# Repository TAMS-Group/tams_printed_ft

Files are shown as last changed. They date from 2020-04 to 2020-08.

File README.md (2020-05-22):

# tams_printed_ft

This repository provides OpenSCAD 3D models together with the corresponding software
to build and assemble a family of low-cost 3D printed force and force/torque sensors.
While multi-axis force/torque sensors are readily available commercially from several vendors,
these a low-volume high-precision devices, and the corresponding costs and complex integration
have so far limited their wide deployment.

Our design approach combines 3D printable plastic structures with commodity optical sensors
and standard Arduino-style microcontrollers. The general sensor configuration, including
type and number of sensors, sensor layout, and structure of the elastic element can be chosen
freely according to the task. We provide a couple of example designs that have been optimized
for 3D printability using common FFF/FDM (fused filament fabrication / fused deposition modeling)
3D machines. The electronics can use custom circuit boards, but many of the sensors can also
be hand-wired without problem, and a working 6-axis force/torque sensor can be built for less
than 20 US dolloars, plus a few hours of 3D printing.

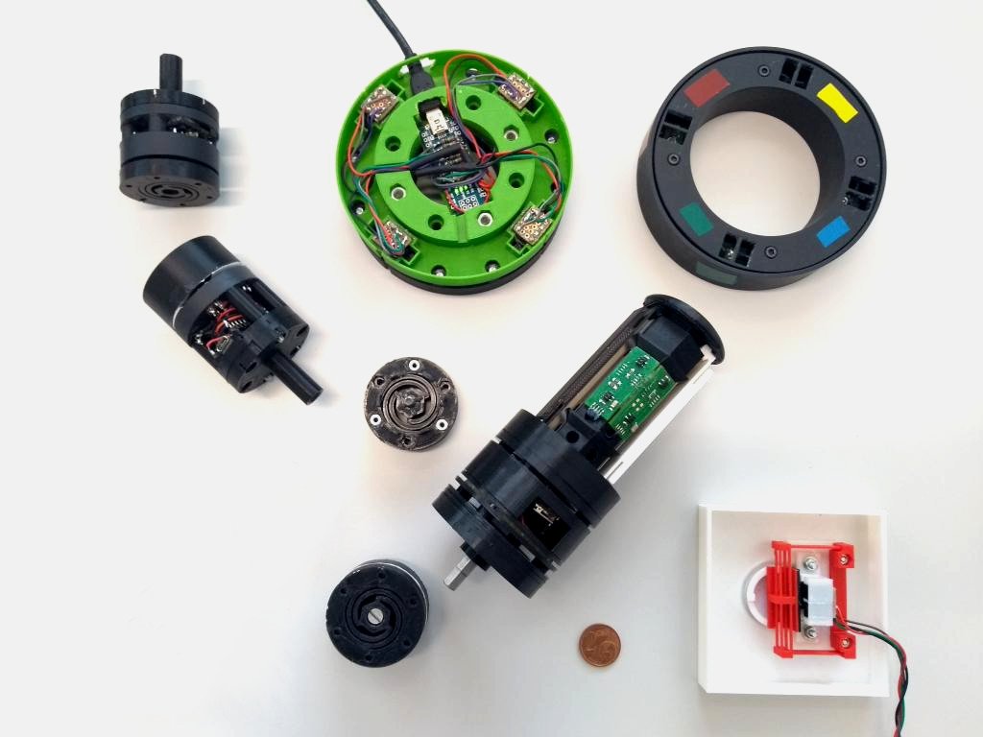
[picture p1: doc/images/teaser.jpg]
"3D printed f/t sensors"


## Note: stub while paper under review

This repository is currently a stub, as the journal paper describing the general approach
and several key algorithms is still under review. If you are a reviewer, please don't hesitate
to contact the authors (via the editors to keep your anonymity) 
for a preview of the final repository contents.

## Getting started

The following instructions assume that you want to build and use a force/torque sensor 
together with ROS. If so, please proceed as follows:

0. read this README and check the overview paper.

1. clone this repository into your catkin workspace, then build your workspace:
```
cd ~/catkin_ws/src
git clone github.com/TAMS-Group/tams_printed_ft
cd ~/catkin_ws
catkin_make
```

2. check the OpenSCAD and/or meshes subdirectories and select the sensor that you need.
Run OpenSCAD and edit the existing parameters or completely modify the sensor geometry.
Export the individual parts to STL meshes.

3. Use your favorite slicing software to convert all needed mechanical parts into G-Code
for your 3D-printer, then start printing the parts.

4. Check that you have the required electronics components (optical sensors, microcontroller,
pullup-resistors, capacitors, ...) and the mechanical components (screws and nuts).

5. Assemble the mechanical parts, insert the optical sensors or ready-made circuit boards,
and wire the optical sensors to the microcontroller/amplifier boards.

6. Connect the microcontroller to the host computer and upload/flash the corresponding
firmware. Modify the firmware according to your needs. Once powered up and flashed,
the microcontroller should start sending out raw sensor data, 
using the selected communication protocol (e.g. I2C/TWI, SPI, UART, USB),
baudrate (e.g. 115200 baud), etc.

7. Edit and update the launch files to match your setup (e.g. name of the root tf frame,
name of your robots and F/T sensor frames, sample rates, comunication device, etc.).

8. Run the ROS driver for the selected sensor, and check that the raw data looks ok:
```
roscore
roslaunch tams_printed_ft bottle_ft.launch  [device:=/dev/ttyUSB2 ...]
rosrun plotjuggler PlotJuggler -> start streaming -> /printed_ft/rawdata -> plot
```

9. Record calibration data
```
roslaunch tams_printed_ft bottle_ft_calibration_helper.launch
run experiment ... press control-c
python3 scripts/linear_bottle.py 
check calibration quality, select best algorithm, ...
cp /tmp/bottle_ft_huber_1e-4.yaml config/bottle_ft_calibration.yaml
```

10. Restart the sensor to use the recently created calibration file

## Directory Structure

What is in here? The basic structure of this repository is a common ROS catkin package, with a few extra directories for the OpenSCAD models and Arduino firmware:

* `config`: ROS configuration files, including example sensor calibration YAML files and rviz / plotjuggler configurations;
* `doc`: Misc documentation, including the overview paper, datasheets for the optical sensors, Arduino pinouts, and
  some images/screenshots;
* `firmware`: Arduino/Teensy source code for the sensor firmware; copy (or symlink) into your `~/Arduino/` folder to use.
* `launch`: ROS launch files for the sensor drivers and utilities;
* `meshes`: this subdirectory holds STL meshes ready for 3D printing for some of the sensors, as well as Collada .dae files needed for the ROS URDF models;
* `openscad`: Configurable OpenSCAD source code for some of our sensors. Most of the files will render an assembled model of the complete sensor, but individual parts can be enabled or disabled using the provided boolean variables. This directory also provides automated export scripts to generate 3D STL meshes for the individual 3D printable files;
* `nodes`: ROS Python driver nodes for the different sensors, as well as calibration scripts and plotting utilities;
* `scripts`: misc shell scripts
* `src`: ROS C++ source files, currently the calibration-helper tool and the radial-pattern generator;
* `urdf`: ROS URDF models for the sensors;
* `package.xml` and `CMakeLists.txt`: the common ROS catkin package description and build files.

Note that there are no header files (yet).

## Prototype sensors

* The most basic sensor consists of a deflecting beam mounted 
  to a suitable support structure, with an optical distance sensor
  (either reflex-type proximity sensor or fork-type interrupter) in between.
  A foot force sensor for a Robocup soccer humanoid:

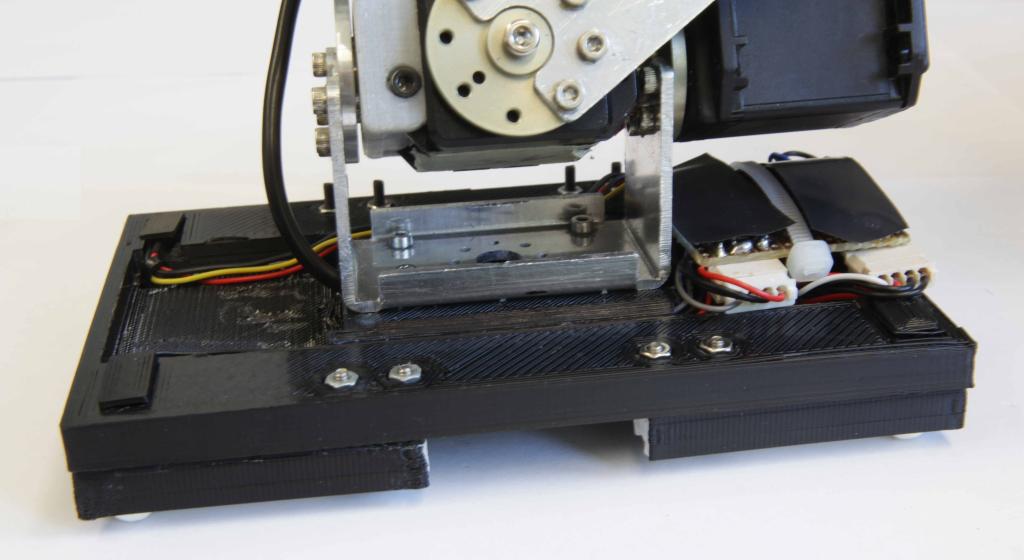
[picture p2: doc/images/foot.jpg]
"Robocup soccer foot sensor"
  

  <!--
  The OpenSCAD module described in our 
  <a href="https://tams.informatik.uni-hamburg.de/publications/2017/3D-Printed%20Low-Cost%20Modular%20Force%20Sensors.pdf">CLAWAR 2017 paper</a>
  can be used to dimension the cantilever for given maximum load.
   -->

* A convenient sensor module built from two fork-type photointerrupters, used as a basic components
  in several of our designs;

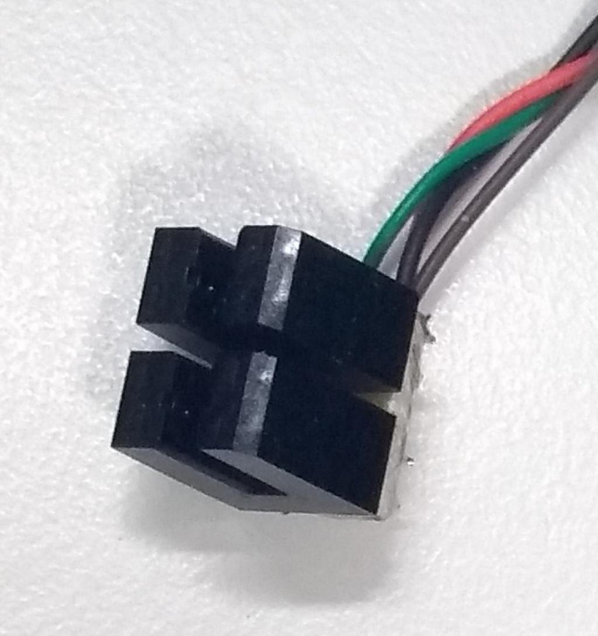
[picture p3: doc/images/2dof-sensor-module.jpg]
"2-DOF sensor module"
  

* One of these modules is than used as the basis of a simple 2-DOF sensor designed
  for measuring friction/shearing forces during object pushing experiments:

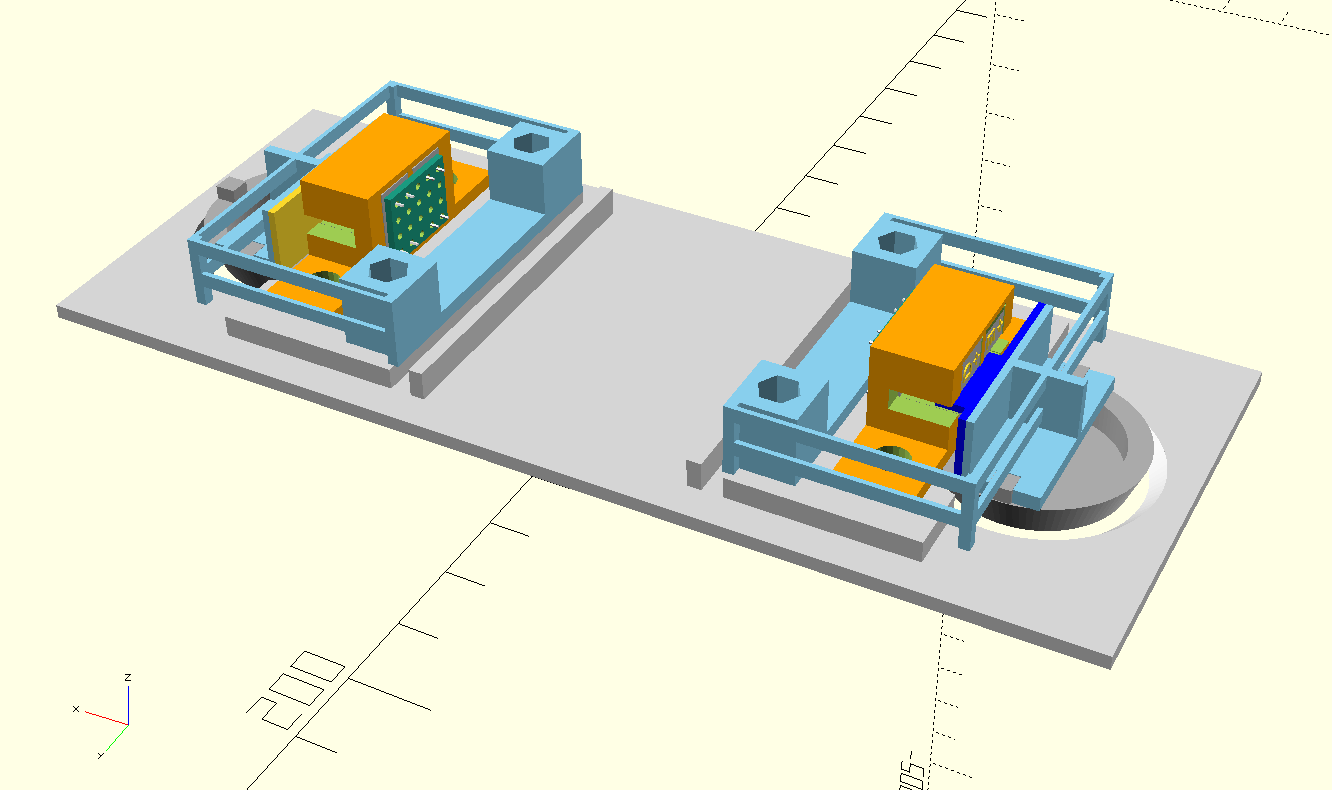
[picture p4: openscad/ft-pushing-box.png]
"pushing-box F/T sensor"
  

* All forces and torque applied to a rigid body can be integrated into one effective 
  net force (Fx,Fy,Fz) and one couple of forces resulting in torque (Mx,My,Mz).
  We include a large diameter six-axis force/torque sensor, using four of the 2-DOF sensor 
  modules presented above and grub-screws for initial zero-adjustment:

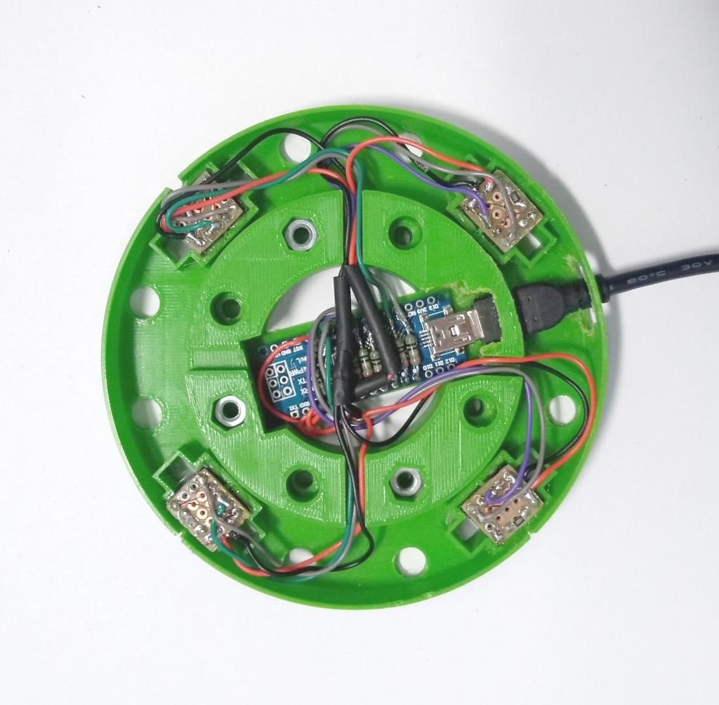
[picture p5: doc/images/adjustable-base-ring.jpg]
"adjustable six-axis F/T sensor"
  

* Unconventional shapes can be designed as well. As an example, we include 
  a ring-type six-axis force/torque sensor, using four 2-DOF sensor modules:

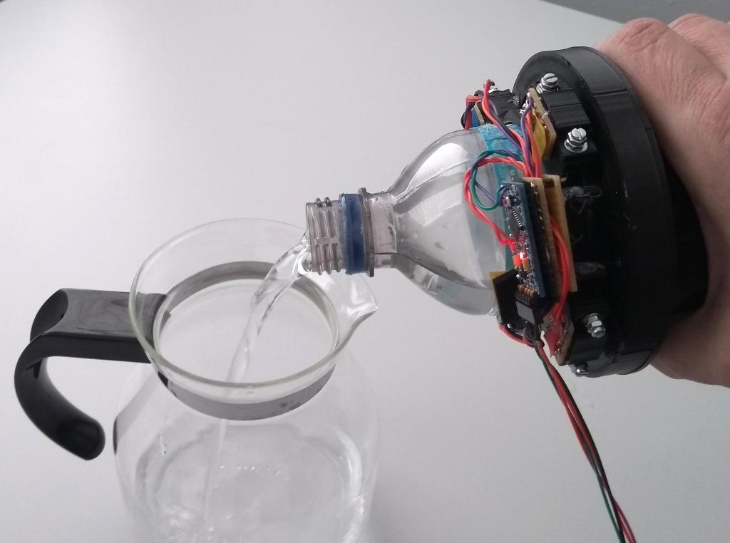
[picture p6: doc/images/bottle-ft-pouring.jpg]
"bottle-ft ring-type six-axis F/T sensor"
  

* 3D-printed springs can be designed at will, exactly matched to the task at hand.
  As an example, we present a 3D-elastic element with three sets of orthogonal levers,
  where force-range and torque-range can be selected individually for each axis.
  The corresponding prototype sensor also demonstrates the use of proximity sensors
  and a flat layout (PCB friendly) of the optical sensors and optional electronics:

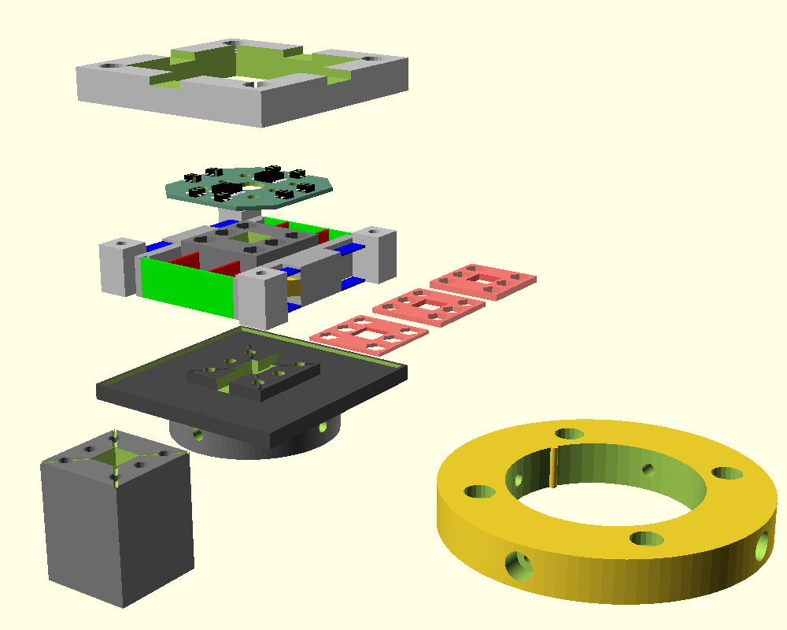
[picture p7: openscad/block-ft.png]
"block-ft six-axis F/T sensor"
  

## OpenSCAD designs and 3D printing

The sensors presented in the paper were all designed using the OpenSCAD software.
We recommend to use OpenSCAD to edit, update, and configure the basic sensor designs to your needs,
but we also provide a set of ready-made STL meshes ready for slicing and printing on your 3D printer.
Most of the meshes are optimized for 3D printability without support structures, 
just make sure to select the appropriate mesh orientation for printing (which should be obvious).
A few STL models contain overhanging parts and bridges; please check for the best mesh orientation
and experiment with different printer settings (including support structures) to find a suitable setup.

## Arduino firmware

While our example designs intentionally use different microcontrollers, 
the core program logic is always the same.
The basic hardware setup consists of a stabilized power supply for the infrared LEDs,
while the phototransistors are connected to pullup resistors and also directly to 
the analog input pins of the selected microcontrollers.

The program first configures the microcontroller output and input pins,
sets up and initializes the communication with the host computer 
and creates the data structures for raw-data filtering.
Communication is typically serial over USB, but also native USB when supported by the controller,
or UDP/WIFI for the wireless boards.

The main loop of the program then repeatedly reads the active analog input pins,
typically staring with one cold read to ensure that the analog voltage has stabilized,
followed by a few AD conversions to digitize the current illumination level.
Optionally, oversampling and filtering is applied.
Where applicable, LEDs might also be pulsed to reduce average power consumption and
to support dark current detection and measurement.

Raw output values are then sent to the host PC, together with sequence number and
health/error indication (overload, ambient light detection, breakage, etc.).
Due ensure high sample rates and low latencies, conversion to floating point 
and calibration is NOT performed on the microcontrollers.

## ROS drivers

## URDF models

We also provide ROS URDF models for the sensors, see the `urdf`subdirectory.
The modeling approach combines the actual (high-res) 3D meshes also used for 3D printing
for the visual model, while a simplified geometric model (cylinder, box) is used for
the sensor collision model.

The sensor model consists of several separate parts, each with their corresponding
TF frames, and linked by joints. Typically, the base frame of the sensor is centered
at the bottom of the static (robot-side) sensor mesh, the sensing joint is in the
middle of the sensor, and another tool-mount frame is provided at the upper end
of the (tool-side) sensor mesh.
We also provide the required yaml controller configuration files to enable
joint_states and wrench output from Gazebo simulation:

```
roscd tams_printed_ft
roslaunch tams_printed_ft gazebo_all_demo.launch
```

The screenshot below shows a collection of URDF sensor models as visualized in rviz:

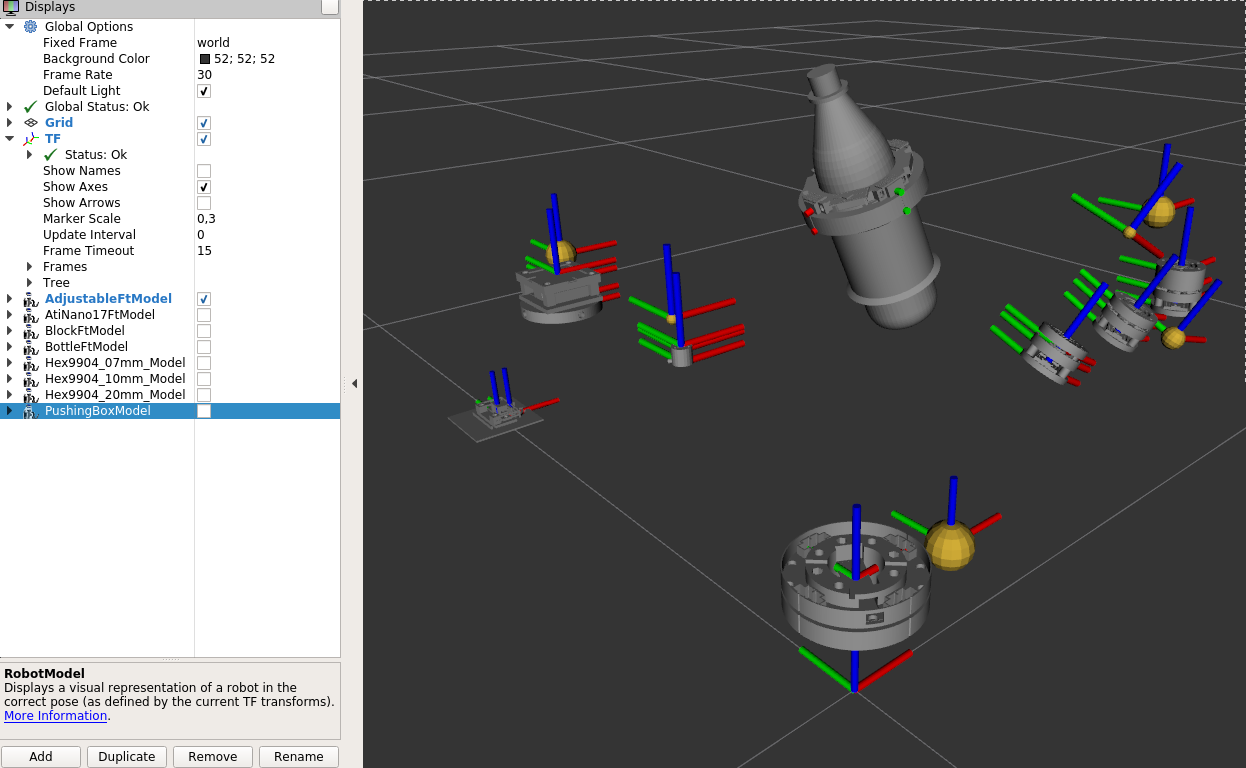
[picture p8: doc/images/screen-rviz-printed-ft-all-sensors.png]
"URDF models of the 3D printed f/t sensors in rviz"


For the small sensors, the tilt under load cannot be ignored, and should be modeled 
using a generic a six-DOF joint between the base (robot side) and swiveling (tool side)
parts of the sensor. 

However, at the moment only single-axis revolute joints are used in the models;
Gazebo will still calculate the complete wrench, but only one axis is actuated
(e.g., roll), while the other axes (e.g. pitch and yaw) remain at zero.

For the real sensor, publishing estimated deflection as `joint_states` message
is planned, but has not been implemented yet. Instead, our sensor launch scripts 
also run `static_transform_publisher` nodes that publish the required transformation
(from sensor base part to deflecting sensor tool part) 
to guarantee a connected tf tree along the kinematic chain. 
By default, we use the all-zero (no deflection, no tilt) transformation, 
but you might want to update the corresponding parameters if your sensor is mostly
used in one orientation and payload.

## Sensor calibration

As described in the paper, all standard approaches can be used to calibrate the sensor(s),
and Python scripts are provided to calculate calibration matrices for a tested sensor.
Calibration against a second reference sensor is of course easiest, and typically only
requires to edit and configure the geometric layout between the 3D printed and the existing
reference sensor in the sensor launch file(s).

## Tips and tricks

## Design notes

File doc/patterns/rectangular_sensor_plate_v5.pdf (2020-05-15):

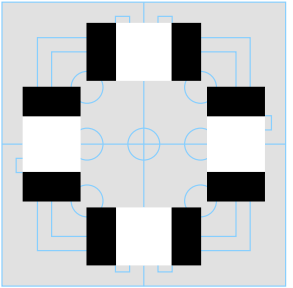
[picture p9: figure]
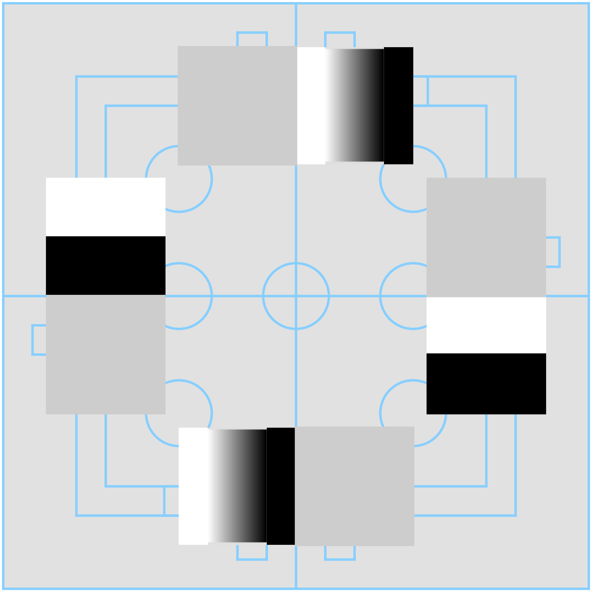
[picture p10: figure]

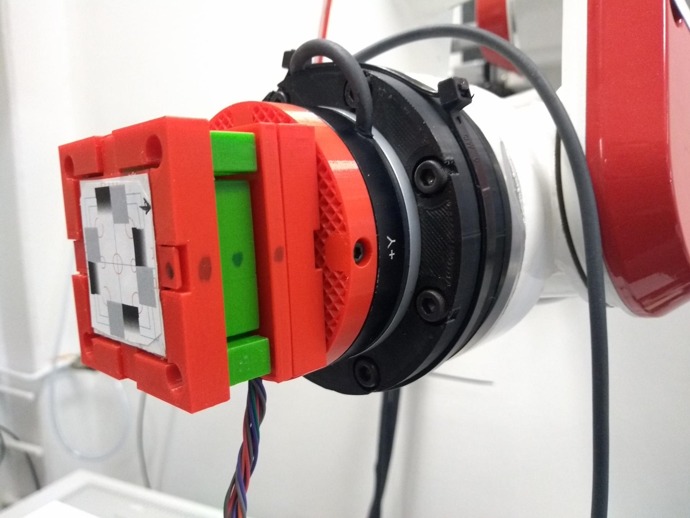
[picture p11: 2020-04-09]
doc/images/block-ft-on-pa10.jpg

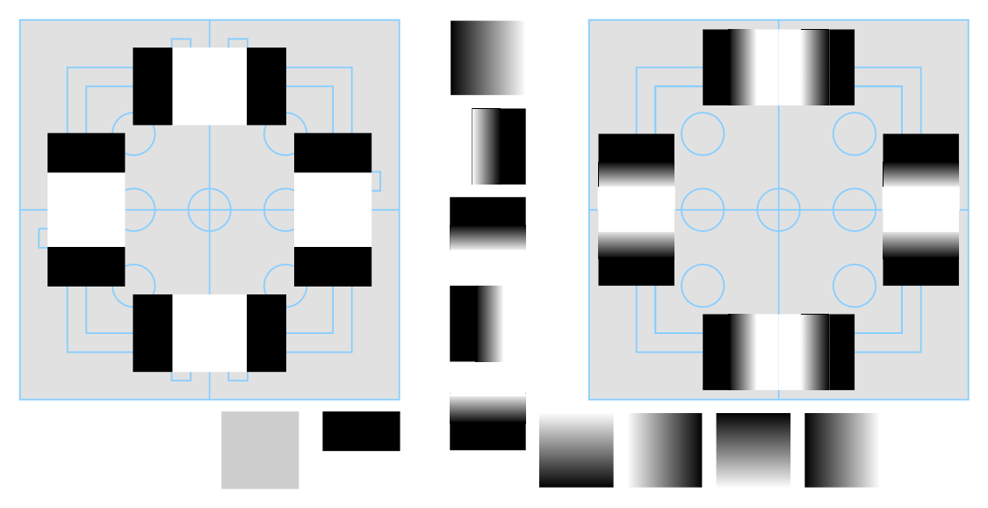
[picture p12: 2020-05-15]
doc/patterns/jfig_rectangular_sensor_plate_v5.png

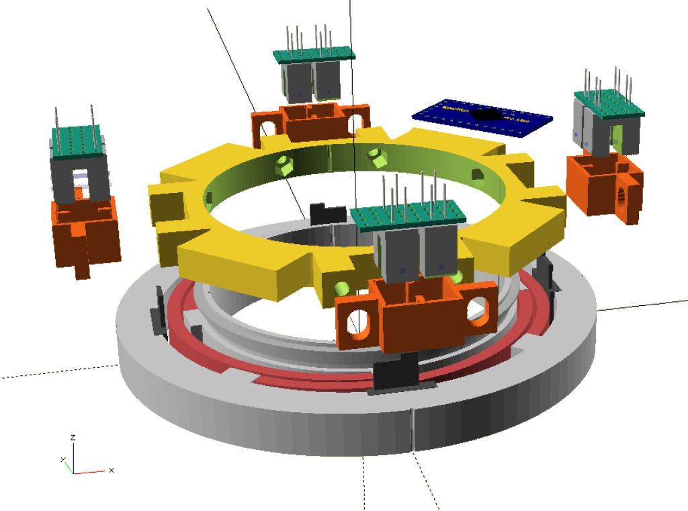
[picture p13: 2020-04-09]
doc/images/bottle-ft-exploded.png

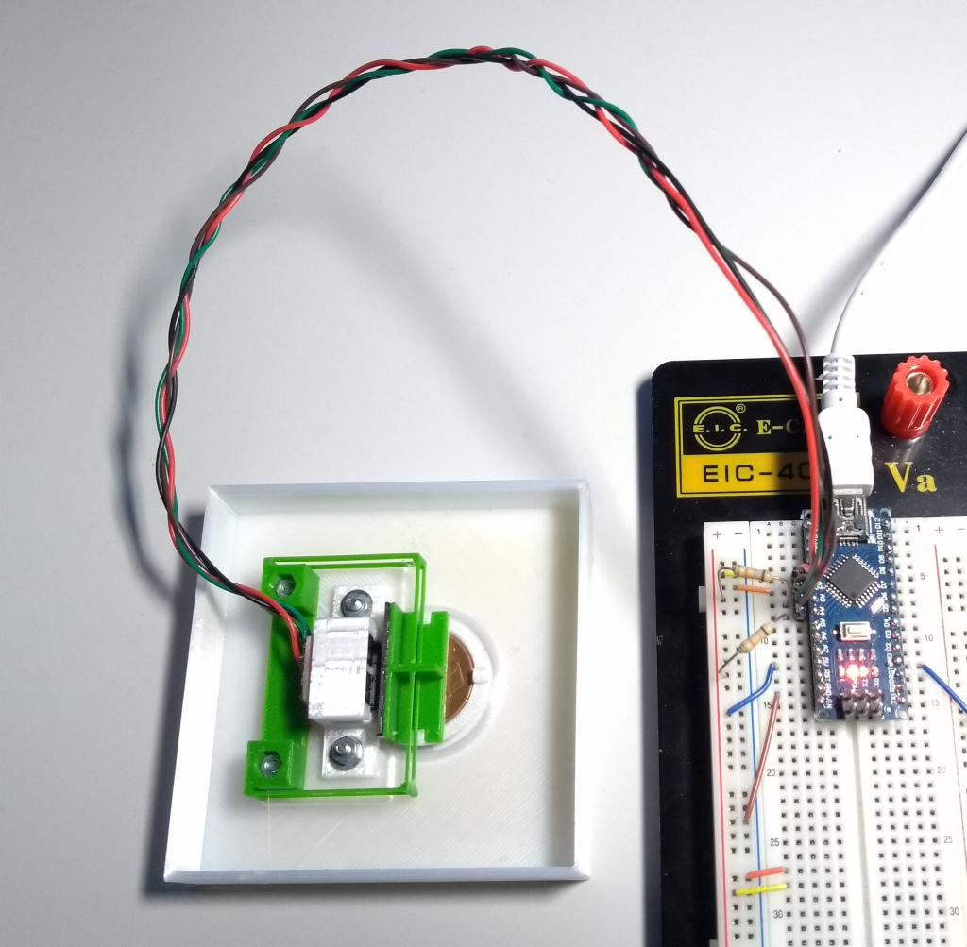
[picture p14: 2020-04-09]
doc/images/pushing-box.jpg

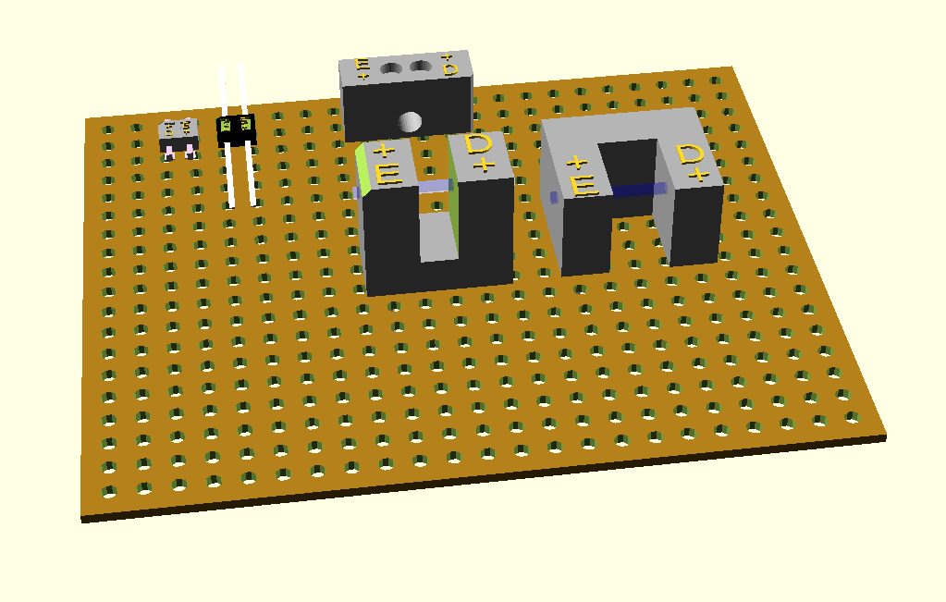
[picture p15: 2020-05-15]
openscad/optokoppler.png

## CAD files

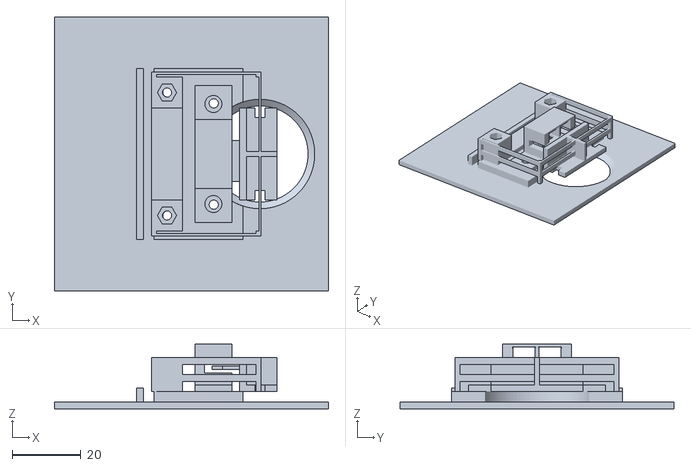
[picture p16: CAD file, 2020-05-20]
openscad/stl/ft-pushing-box-complete-without-probe.stl
80.0 x 80.0 x 18.9

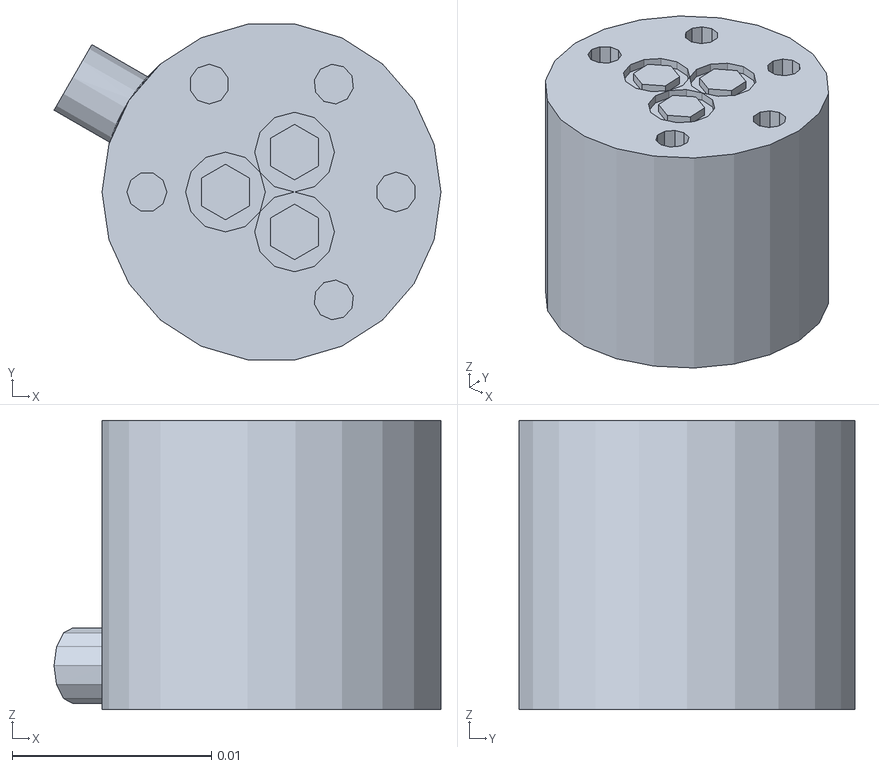
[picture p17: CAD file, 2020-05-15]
meshes/ati_nano17.stl
0.0194 x 0.0168 x 0.0145

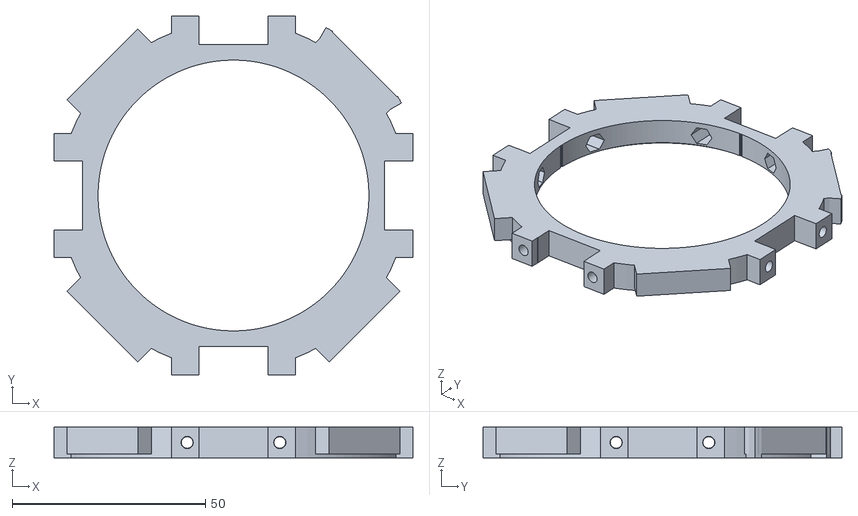
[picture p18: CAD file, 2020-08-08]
openscad/stl/bottle-six-axis-ft-v2-upper-ring-w-carriers.stl
93.0 x 93.0 x 8.00

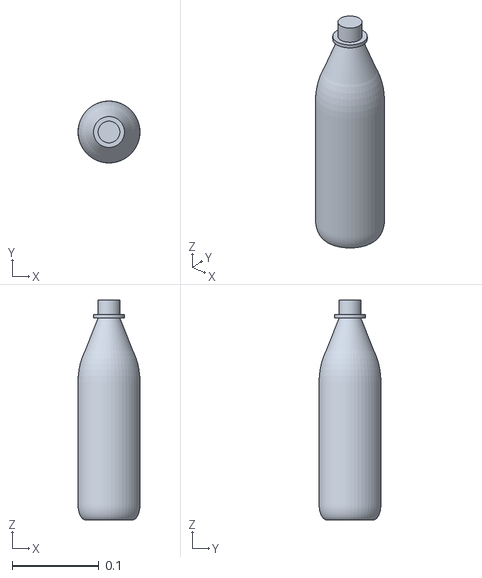
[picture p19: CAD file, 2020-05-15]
meshes/bottle_500ml.stl
0.0714 x 0.0713 x 0.254

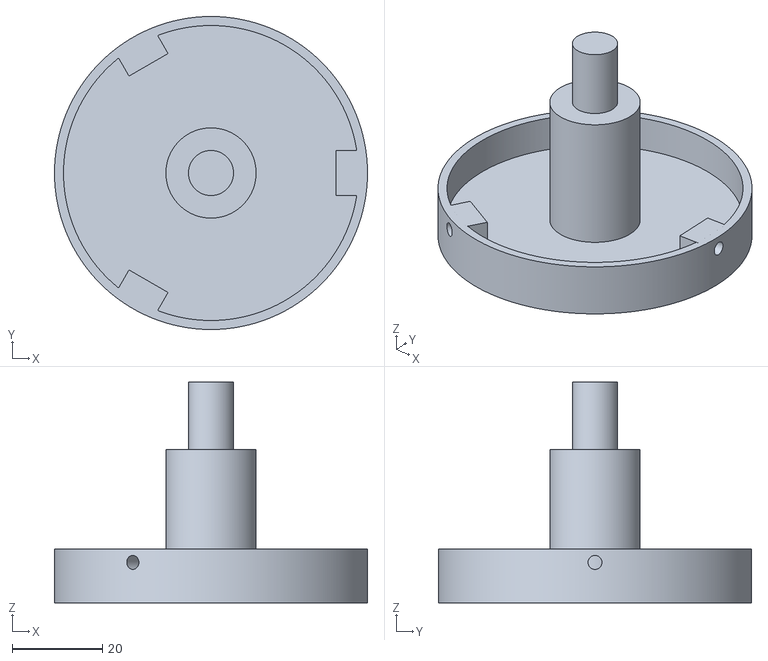
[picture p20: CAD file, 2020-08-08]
openscad/stl/bottle-six-axis-ft-v2-pa10-adapter.stl
69.4 x 69.4 x 49.0

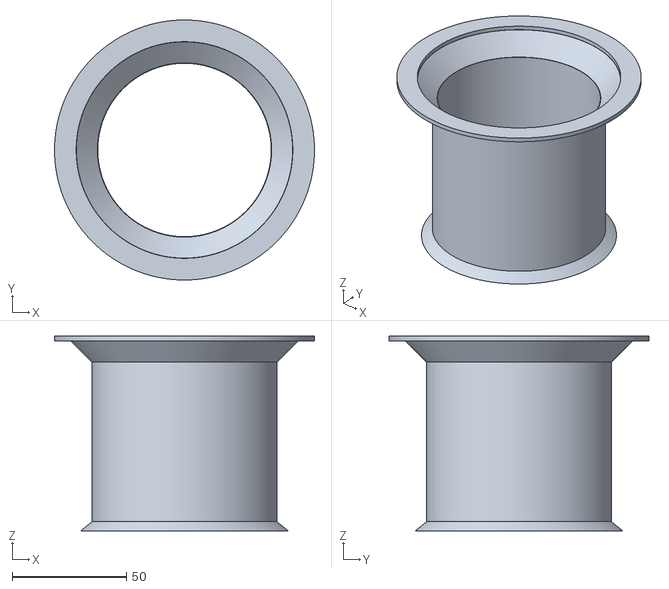
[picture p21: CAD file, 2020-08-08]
openscad/stl/bottle-six-axis-ft-v2-grasp-handle-70mm.stl
114.0 x 114.0 x 85.3

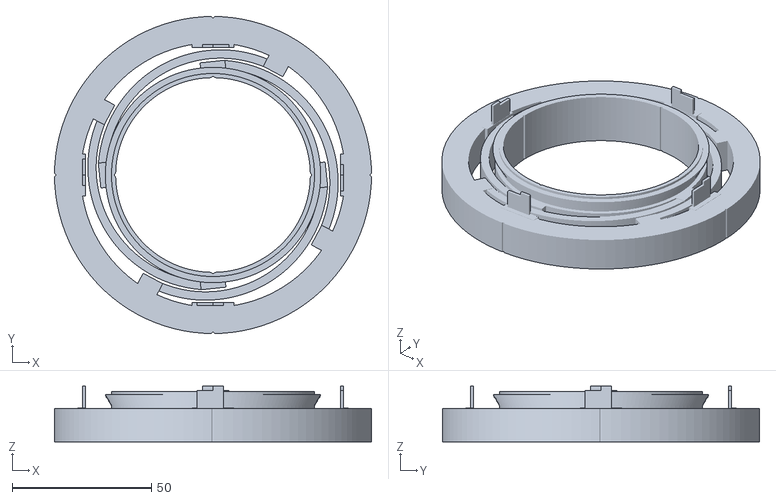
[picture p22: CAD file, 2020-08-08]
openscad/stl/bottle-six-axis-ft-v2-base-ring-h12.stl
114.0 x 114.0 x 20.0

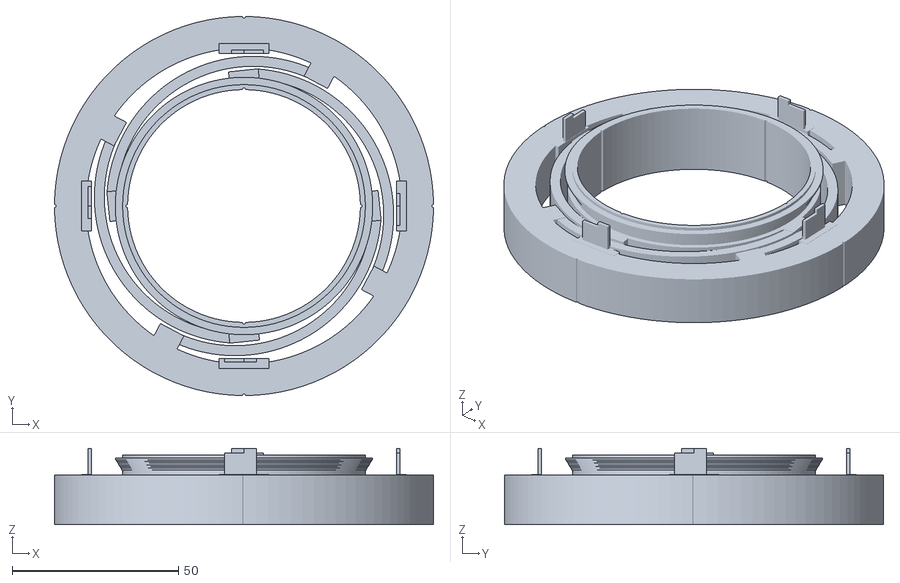
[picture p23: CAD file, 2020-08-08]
openscad/stl/bottle-six-axis-ft-v2-base-ring-h15.stl
114.0 x 114.0 x 23.0

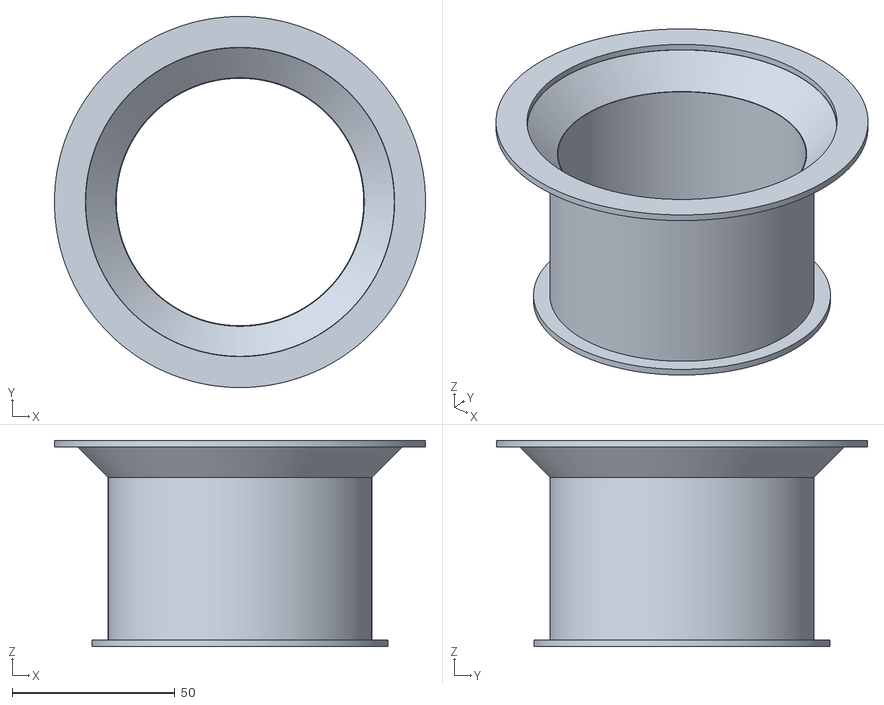
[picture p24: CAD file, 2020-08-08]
openscad/stl/bottle-six-axis-ft-v2-grasp-handle.stl
114.0 x 114.0 x 63.3

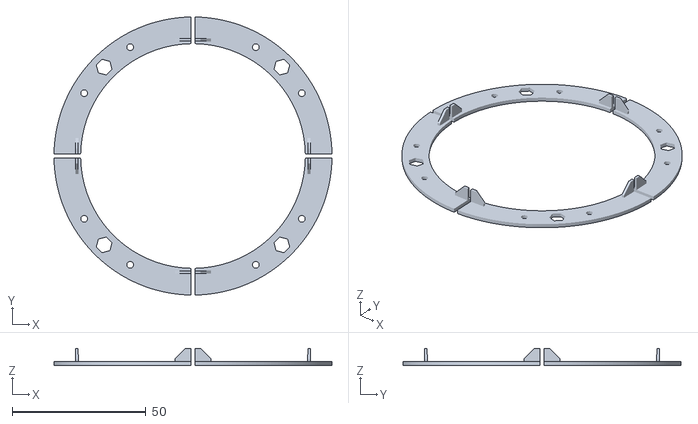
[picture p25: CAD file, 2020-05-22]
openscad/stl/adjustable-ft-v1-fin-ring.stl
104.0 x 104.0 x 6.48

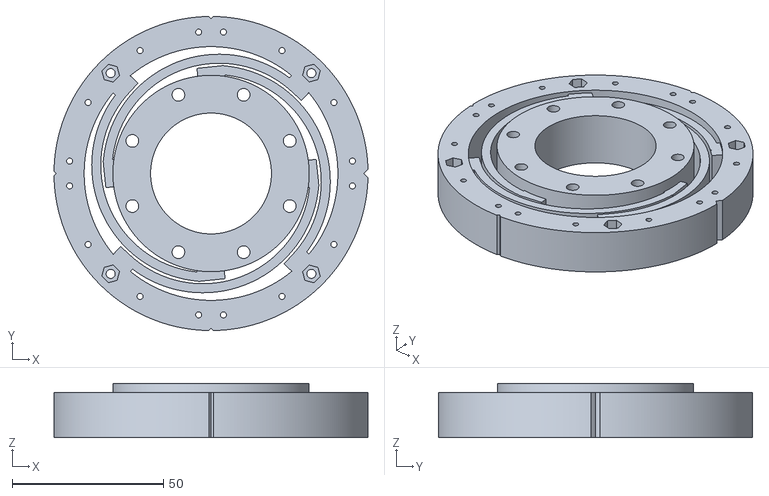
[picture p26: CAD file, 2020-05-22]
openscad/stl/adjustable-ft-v1-base-ring.stl
104.0 x 104.0 x 18.0

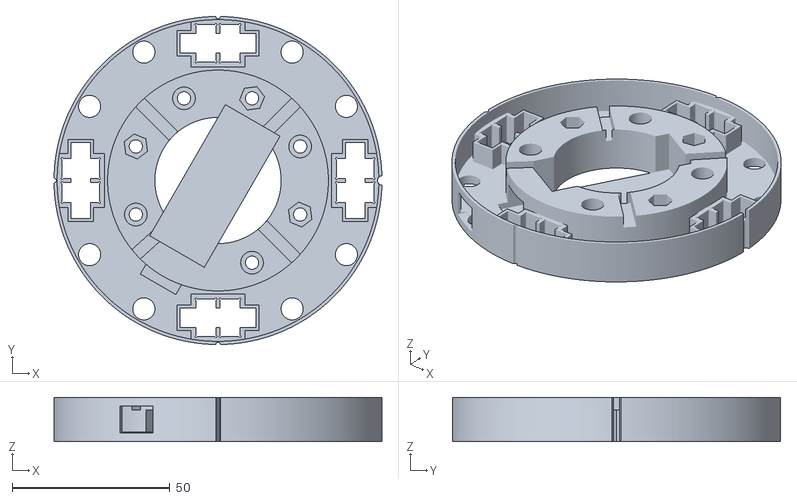
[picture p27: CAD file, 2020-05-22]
openscad/stl/adjustable-ft-v1-upper-ring.stl
104.0 x 104.0 x 14.0

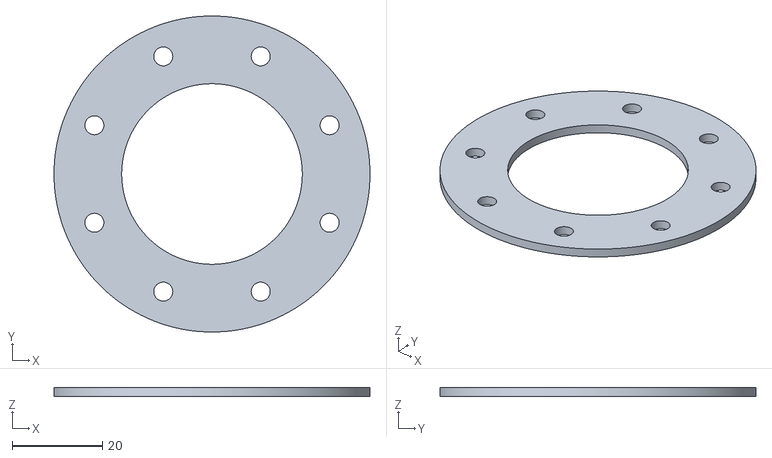
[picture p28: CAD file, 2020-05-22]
openscad/stl/adjustable-ft-v1-distance-ring.stl
70.0 x 70.0 x 2.00

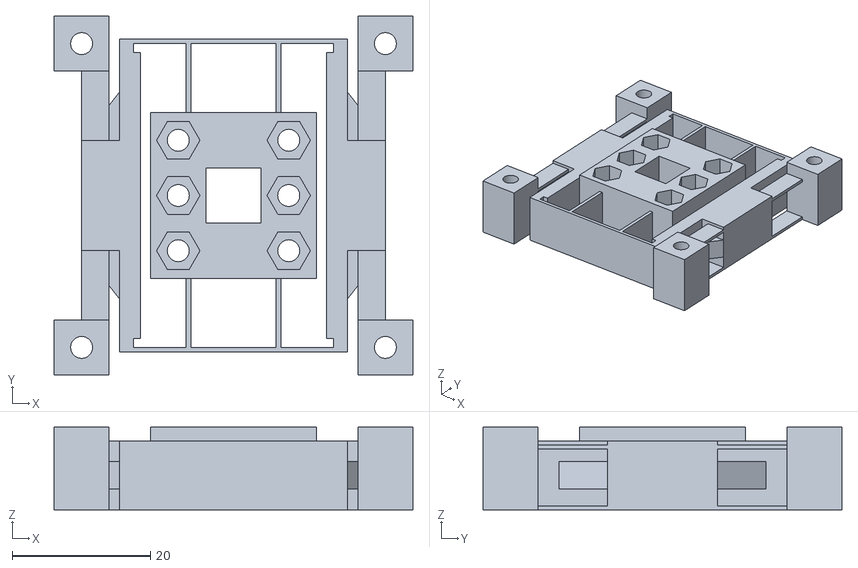
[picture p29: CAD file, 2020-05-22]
openscad/stl/block-ft-x-07-10-13-y-07-7-z-06-10-4.stl
52.0 x 52.0 x 12.0

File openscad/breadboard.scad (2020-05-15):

/* breadboard.scad - 3D models of different prototyping breadboards.
 *
 * 2017.12.24 - refactored into standalone file/module, better params
 * 2017.10.16 - created
 *
 * Note: depending on size, this module generates _a lot_
 * of cylindrical holes. Rendering performance can be an
 * issue, even with fn=10 or so...
 * 
 * (c) 2017, fnh, hendrich@informatik.uni-hamburg.de
 */


// global openscad parameters
eps = 0.01;


// breadboard_demo();
// eurokarte_triple();

module eurokarte_triple() {
  xsize = 160.0;
  ysize = 100.0;
  nx = floor( xsize / 2.54 );
  ny = floor( ysize / 2.54 );
  echo( nx ); echo ( ny );
  xpadding = (xsize - nx*2.54) / 2;
  ypadding = (ysize - ny*2.54) / 2;
  echo( xpadding ); echo( ypadding );

  breadboard( nx=nx, ny=ny, z=0.8, delta=2.54, bore=1.2, fn=12, 
              epoxy=false, triple=true, 
              xpadding=xpadding, ypadding=ypadding );
}


module breadboard_demo() {
translate( [ 0,0,0] ) breadboard( nx=4, ny=9, z=0.8, fn=9, epoxy=false, triple=true );
translate( [15,0,0] ) breadboard( nx=4, ny=3, z=0.8, delta=2.54, single=true, bore=1.0, xpadding=0.0, ypadding=0.0, fn=10 );
translate( [30,0,0] ) breadboard( nx=4, ny=5, z=0.8, delta=2.54, epoxy=false, bore=1.3, xpadding=0.0, ypadding=0.0, fn=10 );
translate( [15,10,0]) breadboard( nx=4, ny=5, z=0.8, delta=1.27, triple=true, bore=0.7, xpadding=0.0, ypadding=0.0, fn=10 );
}



/**
 * Simplified prototyping breadboard. 
 * Origin is at hole(0,0) (=bottom left hole) with the board 
 * extending to (nx-1, ny-1, z), plus any x/y padding.
 */
module breadboard( 
  nx       = 5,     // number of holes in x direction
  ny       = 5,     // number of holes in y direction,
  delta    = 2.54,  // hole spacing
  bore     = 1.3,   // hole diameter
  fn       = 5,     // $fn for hole rendering (performance critical!)
  z        = 0.8,   // board thickness
  xpadding = 0.1,   // extra board space at left/right ends
  ypadding = 0.1,   // extra board space at upper/lower ends,
  epoxy    = true,  // epoxy color (else hartpappe aka paper)
  one_side = true,  // copper only on one side
  triple   = false, // triple-copper-stripes 
  single   = false, // single-copper-dots
  copper_thickness = 0.05, 
  center   = false, 
)
{
  xmin = -delta/2 - xpadding;
  xmax =  (nx-1)*delta + delta/2 + xpadding;
  ymin = -delta/2 - ypadding;
  ymax =  (ny-1)*delta + delta/2 + ypadding;
  // echo( xmin ); echo( xmax ); echo( ymin ); echo( ymax ); echo( delta );
  xx = xmax - xmin;
  yy = ymax - ymin;
  // echo( xx ); echo( yy ); echo( z );

  ddx = (center == true) ? -0.5*(xmax+xmin) : 0;
  ddy = (center == true) ? -0.5*(ymax+ymin) : 0;

  translate( [ddx, ddy, 0] ) 
  difference() {  
    union() {
      // main board
      if (epoxy==true) epoxy() translate( [xmin,ymin,0] ) cube( size=[xx,yy,z], center=false );
      else             hartpappe() translate( [xmin,ymin,0] ) cube( size=[xx,yy,z], center=false );

      // copper holes / stripes (if requested)
      if (single) {
        dxy = (delta - bore) / 3;
        for( ix=[0:1:nx-1] ) {
          for( iy=[0:1:ny-1] ) {
            // echo( ix ); echo( iy );
            copper() 
              translate( [ix*delta-bore/2-dxy,iy*delta-bore/2-dxy,z-eps] ) 
                cube( size=[bore+2*dxy,bore+2*dxy,copper_thickness], center=false );
          }
        }
      }
      else if (triple) { // 3-hole stipes along y direction
        dxy = (delta - bore) / 3;
        for( ix=[0:1:nx-1] ) {
          nny = floor( ny/3 ) * 3;
          for( iy=[0:3:nny-1] ) {
            // echo( ix ); echo( iy );
            copper() 
              translate( [ix*delta-bore/2-dxy,iy*delta-bore/2-dxy,z-eps] ) 
                cube( size=[bore+2*dxy,2*delta+bore+2*dxy,copper_thickness], center=false );
          }
        }
      } // if triple
    } // union

    // the through-holes, diameter "bore", spaced at "delta"
    for( ix=[0:1:nx-1] ) {
      for( iy=[0:1:ny-1] ) {
        // echo( ix ); echo( iy );
        translate( [ix*delta,iy*delta,-eps] ) 
          cylinder( d=bore, h=z+0.1+2*eps, $fn=fn, center=false );
      }
    }
  }

} // end breadboard


module black() {
  color( [0, 0, 0] ) children();
}

module silver() {
  color( [0.9, 0.9, 0.9] ) children();
}

module copper() {
  color( [0.95, 0.7, 0.3] ) children();
}

module epoxy() {
  color( [0.2, 0.7, 0.6] ) children(); 
}

module hartpappe() {
   color( [0.7, 0.5, 0.1] ) children(); 
}

module gray07() {
  color( [0.7, 0.7, 0.7] ) children();
}

module gray02() {
  color( [0.2, 0.2, 0.2] ) children();
}

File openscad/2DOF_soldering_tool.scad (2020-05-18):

/* utility jig for building the "2DOF sensor module" used in some 
   of the prototype sensors. No PCB provided, using a standard 0.1" 
   breadboard works fine. You can, of course, also design a small
   PCB for this, or directly design a larger PCB that carriers 
   multiple sensors.
   
   Insert the TCSTs carefully, then solder the pins to mechanically
   fix the LED and phototransistor inside their housing. Then, you
   might also want to solder-in a series resistor between the two LEDs 
   and perhaps also the pullup-resistors dimensioned for your design.
   Sensor layout can be either parallel or opposite (as shown here,
   in an attempt to avoid direct line-of-sight from an emitter LED
   to the "wrong" phototransistor).
   
   As shown, the PCB/breadboard is one unit ("hole") wider than
   necessary, to provide mechanical contact to the carrier on the
   outside, and also to give you extract soldering positions for
   the external cable. Typical wire would have VCC + GND + 2x signal
   
   Once soldered, carefully extract the two sensors from the jig
   and insert into the corresponding sensor carrier part.
*/

include <breadboard.scad>
include <optokoppler.scad>


pcb_thickness = 1.0;
corner_cutout_diameter = 0.5;

// jfig for building precisely aligned 2-DOF sensor modules
2DOF_sensor_module_soldering_tool();

// for visualization, comment-out when exporting for 3D printing
translate( [30,0,10] ) 2DOF_sensor_module();



/**
 * small plactic holder to help soldering the TCST1103 couplers
 * in precise pose onto the breadboard/sensor PCB.
 */
module 2DOF_sensor_module_soldering_tool() {
  // size of TCST1103 housing
  bx = 11.9;
  by = 6.3;
  bz = 3.1;
  ez = 10.8;

  // correct for overextrusion and irregular FDM surface
  eps = 0.15;

  difference() {
     // main body
     translate( [0,0,ez/2] ) cube( size=[40,40,ez], center=true);
     // cutouts for the TCST 1103 couplers
     translate( [0,-1.5*2.54,ez/2] ) cube( size=[bx+eps,by+eps,ez+eps], center=true );
     translate( [0,+1.5*2.54,ez/2] ) cube( size=[bx+eps,by+eps,ez+eps], center=true );
     // extra corner cutouts for reliable printing on FDM/FFF machines
     for( dx=[ -bx/2, +bx/2 ] )
       for( dy=[ -by-0.25*2.54, -0.25*2.54, 0.25*2.54, 0.25*2.54+by] )
         translate( [dx,dy,ez/2] )
           cylinder( d=corner_cutout_diameter, h=ez+3*eps, center=true, $fn=30 );
  }
}


/** 
 * a small (4x8 holes) breadboard to carry two Vishay TCST1103 
 * optocouplers. The slots are aligned along the y-axis.
 * When mechanically inserted into the sensor base plate, 
 * this serves to measure y- and z-deflection of one elastic arm.
 * Note: The origin of this assembly is at the bottom-left hole (bore)
 * of the breadboard. 
 * Cables are expected to be soldered from the bottom, or into
 * the "extra" four holes at ny=7.
 */
module 2DOF_sensor_module() {
    dx1 =  1.5 * 2.54; // x and y offsets of the optocouplers
    dy1 =  1.5 * 2.54;    
    dy2 =  4.5 * 2.54;    

    translate( [0,0, 0] ) breadboard( nx=4, ny=7, z=pcb_thickness, bore=1.0, fn=15, epoxy=false );
    translate( [dx1, dy1, pcb_thickness] ) rotate( [0,0,180] ) vishay_TCST1103();
    translate( [dx1, dy2, pcb_thickness] ) rotate( [0,0,0] ) vishay_TCST1103();
}

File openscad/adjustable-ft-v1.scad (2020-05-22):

/** adjustable-ft-v1.scad
 * 
 * 2020.02.06 - inner ring to match Sunrise M3207 sensor
 * 2020.02.05 - new (copied from bottle-ft-v2)
 *
 * (c) 2019,2020 fnh, hendrich@informatik.uni-hamburg.de
 */
 
 // see end of file for our #include's...

eps = 0.01;
fn  = 250;

fdm_fudge = 0.2; // extra size for bores/holes/nuts due to shrinkage

explode_distance = 20; // 29; // 0 10 20 50;
arduino_explode_distance = 25; // 15;

pcb_thickness = 1.0;



// select components and options.
// Enable one or more of these before exporting to STL:
//

make_base_ring      = true;              // bottom + spiral parts of the FT
base_ring_inbus_instead_of_grub_screws = true;

make_fin_ring       = true;
make_spare_fins     = false;

make_upper_ring     = true;              // upper (optical sensor mounting) part
make_central_arduino_plate = true;
make_arduino_cutout = true;
show_sensors        = true;

make_arduino_ring   = false;
show_arduino_nano   = true;

make_distance_ring  = false;




// enable/disable optional components, check before exporting to STL:
//
use_colors = true;
h_inner = 18;
h_outer = 15;
h_fin_ring = 1;

show_sensor_blocks    = false;
cutout_sensor_blocks  = false;
show_sensor_carriers  = false;
show_arduino_pro_mini = false;


// main dimensions
//

M2NUTs = 4;    // diameter across sides
M2NUTe = 4.38; // outer diameter across edges
M2NUTm = 1.6;  // nut height
M2BORE = 2.0;
M2SCREWdk = 3.8; // inbus screw head diameter
M2SCREWk  = 2.0; // inbus screw head height

M25NUTs = 5;
M25NUTe = 5.45;
M25NUTm = 2;
M25BORE = 2.5;
M25SCREWdk = 4.5; // inbus screw head diameter
M25SCREWk  = 2.5; // inbus screw head height

M3NUTs = 5.5;
M3NUTe = 6.08;
M3NUTm = 2.4;
M3BORE = 3.0;   // add fudge / redefine on command line as neede
M3SCREWdk = 5.5; // inbus screw head diameter
M3SCREWk  = 3.0; // inbus screw head height

M4NUTs = 7.0;
M4NUTe = 7.8;
M4NUTm = 3.2;
M4BORE = 4.0;
M4SCREWdk = 7.0; // inbus screw head diameter
M4SCREWk  = 4.0; // inbus screw head height

M5NUTs = 8.0;
M5NUTe = 8.63;
M5NUTm = 4.0;
M5BORE = 5.0;
M5SCREWdk = 8.5; // inbus screw head diameter
M5SCREWk  = 5.0; // inbus screw head height



 
 
//intersection() 
//{
// translate( [0,0,-0] ) 
//   cube( size=[110.0,140,50], center=true ); // 90,140,50
//  
//// translate( [0,0,0] ) cube( size=[90.0,140,50], center=true ); // 90,140,50
{
union() { 


if (make_base_ring) {
base_ring( 
  h_inner = h_inner,
  d_inner1 = 40,   // same as Sunrise M3207 & PA10-6C flange
  d_inner2 = 65,   // Sunrise M320745,135,225,315]
  inner_screw_radius = 28.2,
  // inner_screw_angles = [45,135,225,315]
  inner_screw_angles = [22.5, 67.5, 112.5, 157.5, 202.5, 247.5, 292.5, 337.5],
  inner_screw_modes  = [0,1,0,1,0,1,0,2], // 0=bore, 1=bottom-head-cavity 2=bottom-hex-nut-cavity
  inner_screw_bore = M4BORE + 0.2,
  inner_screw_head_cavity_height = M4SCREWk + 0.5,
  inner_screw_head_cavity_diameter = M4SCREWdk + 0.2,
  inner_screw_hex_cavity_diameter = M4NUTe + 0.2,
  h_outer = h_outer,
  d_outer1 = 84,   // inner diameter of outer (moving) ring
  d_outer2 = 104,  // outer diameter of outer (moving) ring,
  outer_screw_radius = (84+104)/4, // (d_outer1 + d_outer2)/2,
  outer_screw_angles = [45,135,225,315],
  // v1 grub_screw_angles = [-5,+5,80,100,170,190,260,280],
  grub_screw_angles = [-5,+5,85,95,175,185,265,275],
  grub_screw_bore = M2BORE,
  lever_fixing_screw_angles = [-30,30,60,120,150,210,240,300],
  spring_thickness = h_outer-1
  );
}
  

if (make_fin_ring) {
translate( [0,0,h_outer + explode_distance + eps] ) 
fin_ring(
  h_fin_ring = 1.5, // h_fin_ring,
  d_outer1 = 84,   // inner diameter of outer (moving) ring
  d_outer2 = 104,  // outer diameter of outer (moving) ring,
  outer_screw_radius = (84+104)/4, // (d_outer1 + d_outer2)/2,
  outer_screw_angles = [45,135,225,315],
  // grub_screw_angles = [-7,+7,80,100,172,188,260,280],
  grub_screw_angles = [-7,+7,83,97,173,187,263,277],
  grub_screw_bore = M2BORE,
  lever_fixing_screw_angles = [-30,30,60,120,150,210,240,300],

  fin_radius = 90/2-1.5, // was: 90/2
  fin_angles = [-1,+1,89,91,179,181,269,271],
  fin_orientations = [180,0,180,0,180,0,180,0],
  fin_base_height = 1,
  fin_thickness = 1,
  fin_height = 4,       // was: 9
  fin_width = 6
  );
}



if (make_upper_ring) {
translate( [0,0,h_inner + 2*explode_distance + 0.7*eps] )
upper_ring( 
  h_inner = 14,
  d_inner1 = 40,   // same as Sunrise M3207 & PA10-6C flange
  d_inner2 = 70,  // was 65,
  inner_screw_radius = 28.2,
  inner_screw_angles = [22.5, 67.5, 112.5, 157.5, 202.5, 292.5, 337.5],
  inner_screw_modes  = [1,2, 1,2, 1, 1,2], // 0=bore, 1=upper-cavity 2=upper-hex-cavity
  // inner_screw_angles = [22.5, 67.5, 112.5, 157.5, 202.5, 247.5, 292.5, 337.5],
  // inner_screw_modes  = [1,2, 1,2, 1,2 ,1,2], // 0=bore, 1=upper-cavity 2=upper-hex-cavity
  inner_screw_bore = M4BORE + 0.2,
  inner_screw_head_cavity_height = M4SCREWk + 2.5,
  inner_screw_head_cavity_diameter = M4SCREWdk + 0.2,
  
  h_outer = h_outer,
  d_outer1 = 84,   // inner diameter of outer (moving) ring
  d_outer2 = 104,  // outer diameter of outer (moving) ring,

  outer_screw_radius = (84+104)/4, // (d_outer1 + d_outer2)/2,
  outer_screw_angles = [45,135,225,315],

  lever_fixing_screw_angles = [-30,30,60,120,150,210,240,300],
  spring_thickness = h_outer-1,

  cable_channels = [45, 135, 222, 315],
  h_cable_channels = 4,

  arduino_angle = 60,  
  h_arduino_base_plate = 1
  );
  
  
  if (h_inner < (h_outer + h_fin_ring)) {
    echo( "ERROR: h_inner < (h_outer + h_fin_ring)", h_inner, h_outer, h_fin_ring ); 
  }
}


if (make_arduino_ring) { 
translate( [0,0,h_inner+13 + 3*explode_distance + 0.7*eps] )
arduino_ring(
  h_inner  = 8,
  d_inner1 = 40,   // same as Sunrise M3207 & PA10-6C flange
  d_inner2 = 70,  // was 65,
  inner_screw_radius = 28.2,
  inner_screw_angles = [22.5, 67.5, 112.5, 157.5, 202.5, 247.5, 292.5, 337.5],
  inner_screw_modes  = [1,2, 1,2, 1,2 ,1,2], // 0=bore, 1=upper-cavity 2=upper-hex-cavity
  inner_screw_bore = M4BORE + 0.2,
  inner_screw_head_cavity_height = M4SCREWk + 0.5,
  inner_screw_head_cavity_diameter = M4SCREWdk + 0.2
);
}


if (make_distance_ring) {
h_distance_ring = 2.0;
 translate( [0,0,2*h_inner + 3.3*explode_distance + 0.5*eps] )
// translate( [0,0,h_inner + 0.9*explode_distance + 0.5*eps] )
distance_ring( 
  h = h_distance_ring,
  d_inner1 = 40,   // same as Sunrise M3207 & PA10-6C flange
  d_inner2 = 70,  // was 65,
  inner_screw_radius = 28.2,
  inner_screw_angles = [22.5, 67.5, 112.5, 157.5, 202.5, 247.5, 292.5, 337.5],
  inner_screw_bore = M4BORE + 0.2
);
}

if (make_spare_fins) { spare_sensor_fins(); } 



}} // union; intersection









/**
 * the adjustable-fins ring to be screwed/glued on top of the base ring.
 * Fin height is originally as specified, but can then be raised a bit
 * turning the grub-screws inserted into the base ring.
 * 
 * Most parameters are expected to be the same as for base ring,
 * but fin height is of course the most important parameter here.
 */
module fin_ring(
  h_fin_ring = 1,
  d_outer1 = 95,   // inner diameter of outer (moving) ring
  d_outer2 = 120,  // outer diameter of outer (moving) ring,
  outer_screw_radius = (95+120)/4, // (d_outer1 + d_outer2)/2/2
  outer_screw_angles = [45,135,225,315],
  grub_screw_angles = [-5,+5,80,100,170,190,260,280],
  lever_fixing_screw_angles = [-30,30,60,120,150,210,240,300],
  lever_fixing_screw_bore = M25BORE,
  fin_angles = [-5,+5,80,100,170,190,260,280],
  fin_radius = (95+120)/4,
  fin_thickness = 1,
  fin_width = 3,
  fin_crop_height = 8,
  fin_base_height = 1, 
  fin_orientations = [180,0,180,0,180,0,180,0]
)
{
  color( "lightblue" )
  difference() {
    ring( d_inner=d_outer1, d_outer=d_outer2, h=h_fin_ring, center=false, fn=200 );

    translate( [0,0,h_fin_ring/2] ) 
      cube( size=[d_outer2+eps,h_fin_ring+eps,h_fin_ring+eps], center=true );
    translate( [0,0,h_fin_ring/2] ) 
      cube( size=[h_fin_ring+eps,d_outer2+eps,h_fin_ring+eps], center=true );

    // M3 screw bores
    for( theta=outer_screw_angles ) {
      rotate( [0,0,theta] ) 
        translate( [outer_screw_radius, 0, -eps/2] ) 
          rotate( [0,0,30] )
            cylinder( d=M3NUTe, h=h_fin_ring+eps, center=false, $fn=6 );
    }
    
    // bores to fix fin-ring on base-ring
    for( theta=lever_fixing_screw_angles ) {
      rotate( [0,0,theta] ) 
        translate( [outer_screw_radius, 0, -eps/2] ) 
          cylinder( d=lever_fixing_screw_bore, h=h_fin_ring+eps, center=false, $fn=50 );
    }
  }  

  fin_v1 = false;
  fin_v2 = true;
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

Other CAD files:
openscad/stl/block-ft-cover-ring-40-height-10.stl
openscad/stl/block-ft-x-07-10-15-y-07-7-z-06-10-6.stl
openscad/stl/block-ft-cover-ring-40-height-8.stl
openscad/stl/block-ft-base-holder.stl
openscad/block-ft.scad
openscad/bottle-six-axis-ft-v2.scad
openscad/electronics.scad
openscad/ft-pushing-box.scad
openscad/optokoppler.scad
openscad/spacemouse-9904.scad
openscad/stl/2DOF_soldering_tool.stl
openscad/stl/adjustable-ft-v1-distance-ring-2mm.stl
openscad/stl/block-ft-base-plate.stl
openscad/stl/block-ft-cover-ring-40-height-9.stl
openscad/stl/block-ft-fake-pcb-40.stl
openscad/stl/block-ft-m3207-adapter-outer.stl
openscad/stl/block-ft-pattern-plate-40.stl
openscad/stl/block-ft-x-07-10-11-y-07-9-z-06-10-6.stl
openscad/stl/block-ft-x-07-10-9-y-07-10-z-06-10-8.stl
openscad/stl/ft-pushing-box-bottom-plate.stl
openscad/stl/ft-pushing-box-coins-holder.stl
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

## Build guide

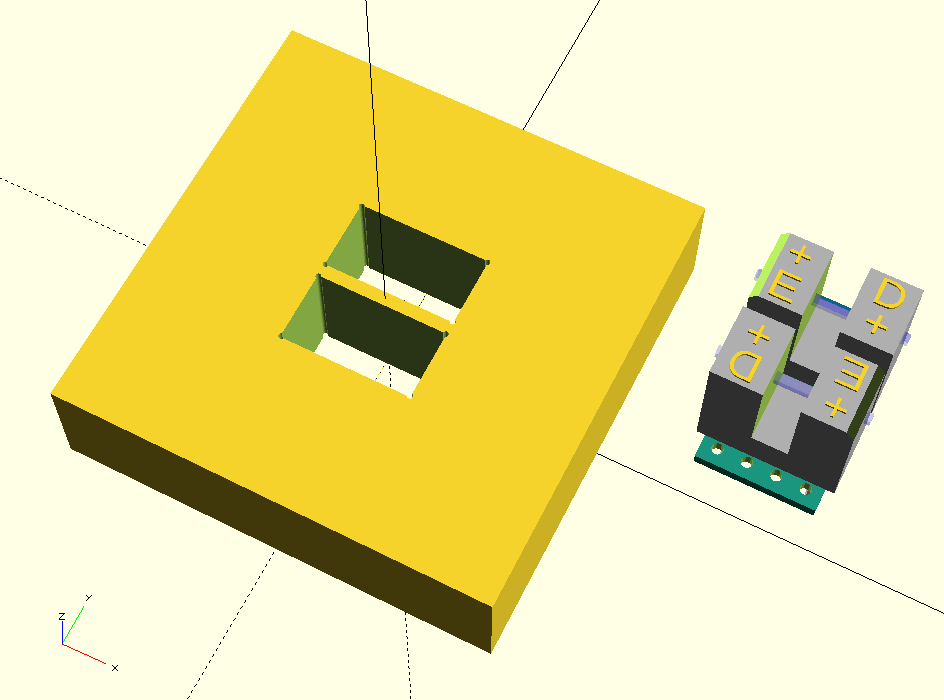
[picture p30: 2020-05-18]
openscad/2DOF_soldering_tool.png

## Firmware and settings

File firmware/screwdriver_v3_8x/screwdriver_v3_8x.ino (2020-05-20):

/* screwdriver_v3_8x.ino
 *  
 * Example firmware for the "Instrumented Screwdriver" sensing object
 * with the Arduino Nano 33 IOT board. Measures gyro+acc, 5x tool forces, 
 * 12x grasp forces from on-board IMU and multiplexed optical proximity 
 * sensors. Data is written to Serial (if connected) and sent via WiFi UDP.
 * 
 * Using fast analogRead() with 8x oversampling and median-filtering
 * to reduce the Wifi-induced noise.
 * 
 * 2020.05.13 - updated (add 8x oversampling and median filtering)
 * 2020.04.15 - updated (v2)
 * 2019.08.21 - created
 * 
 * (C) 2019, 2020,   fnh, hendrich@informatik.uni-hamburg.de
 */


#include <SPI.h>
#include <WiFiNINA.h>
#include <WiFiUdp.h>
#include <Arduino_LSM6DS3.h>   // IMU
#include "arduino_secrets.h"   // Wifi password. Provide your own values here.


// main configuration options: do we want serial communication?
// do we want WiFI communication?
// 
unsigned int try_serial = 1;
unsigned int have_serial = 0; 
unsigned int use_wifi = 1;
unsigned int use_wifi_input = 0;

#define debug 0
#define LED_PIN 13


// maximum number of tries/wait seconds to open Serial port
#define MAX_SERIAL_ATTEMPTS 10     

// WIFI stuff 
int status = WL_IDLE_STATUS;

char ssid[] = SECRET_SSID;     // your network SSID (name)
char pass[] = SECRET_PASS;     // your network password (use for WPA, or use as key for WEP)
int keyIndex = 0;              // your network key Index number (needed only for WEP)


unsigned int localPort = 11333; // local port to listen for UDP packets
IPAddress tamsXXX( 192, 168, 0, 1 );
WiFiUDP   Udp;   // UDP instance to send and receive packets over UDP



#define PACKET_SIZE   255
char packetBuffer[ PACKET_SIZE]; //buffer to hold incoming and outgoing packets
char* pp = packetBuffer;   // packet-pointer: active char in buffer




const int adc_warmup = 1; // was: 3 // extra initial ADC reads before actual read

// analog channels for screwdriver tool forces
int force0, force1, force2, force3, force4, force5;

// analog channels for screwdriver grasping handle
int touch_0_lower, touch_0_upper;
int touch_1_lower, touch_1_upper;
int touch_2_lower, touch_2_upper;
int touch_3_lower, touch_3_upper;
int touch_4_lower, touch_4_upper;
int touch_5_lower, touch_5_upper;


unsigned int iteration = 0;


// if needed, scale IMU values back from float to (signed int 16),
// current library sets 2000 deg/sec gyro range and 4G acc range, 104 Hz,
// see ~/Arduino/Libaries/Arduino_Arduino_LSM6DS3/src for sources...
// 
#define GYRO_TO_INT   (32768.0 / 2000.0)
#define ACC_TO_INT    (32768.0 / 4.0)


void msg( String s ) {
  if (have_serial) Serial.println( s );
}


/**
 * generate a diagnostic blink pattern on build-in LED (pin 13),
 * with the given number of long (500 msec) blinks, followed by
 * short (200 mesc) blinks, repeated n times.
 */
void info_blink_led( int n_long, int n_short, int b_repetitions ) {
  for( int i=0; i < max( 1, b_repetitions); i++ ) {
    for( int j=0; j < n_long; j++ ) {
      digitalWrite( LED_PIN, HIGH );
      delay( 500 );
      digitalWrite( LED_PIN, LOW );
      delay( 200 );
    }
    for( int j=0; j < n_short; j++ ) {
      digitalWrite( LED_PIN, HIGH );
      delay( 200 );
      digitalWrite( LED_PIN, LOW );
      delay( 200 );
    }
  } // for i
}


/** 
 * Outputs a diagnostic blink pattern on built-in LED (pin 13):
 * count short (0.2 sec) blinks, followed by 1 sec dark.
 * Note: this function does NOT return.
 */
void error_blink_forever( int count ) {
  pinMode( 13, OUTPUT );
  
  while( 1 ) {
    for( int i=0; i < count; i++ ) {
      digitalWrite( 13, HIGH );
      delay( 200 );
      digitalWrite( 13, LOW );
      delay( 200 );
    }
    delay( 1000 );
  }
}


// Array A[] has the items to sort; array B[] is a work array.
void TopDownMergeSort(int A[], int B[], int n)
{
    CopyArray(A, 0, n, B);           // one time copy of A[] to B[]
    TopDownSplitMerge(B, 0, n, A);   // sort data from B[] into A[]
}


// Sort the given run of array A[] using array B[] as a source.
// iBegin is inclusive; iEnd is exclusive (A[iEnd] is not in the set).
void TopDownSplitMerge( int B[], int iBegin, int iEnd, int A[])
{
    if(iEnd - iBegin < 2)                       // if run size == 1
        return;                                 //   consider it sorted
    // split the run longer than 1 item into halves
    int iMiddle = (iEnd + iBegin) / 2;              // iMiddle = mid point
    // recursively sort both runs from array A[] into B[]
    TopDownSplitMerge(A, iBegin,  iMiddle, B);  // sort the left  run
    TopDownSplitMerge(A, iMiddle,    iEnd, B);  // sort the right run
    // merge the resulting runs from array B[] into A[]
    TopDownMerge(B, iBegin, iMiddle, iEnd, A);
}

//  Left source half is A[ iBegin:iMiddle-1].
// Right source half is A[iMiddle:iEnd-1   ].
// Result is            B[ iBegin:iEnd-1   ].
void TopDownMerge(int A[], int iBegin, int iMiddle, int iEnd, int B[])
{
    int i = iBegin; int j = iMiddle;
 
    // While there are elements in the left or right runs...
    for (int k = iBegin; k < iEnd; k++) {
        // If left run head exists and is <= existing right run head.
        if (i < iMiddle && (j >= iEnd || A[i] <= A[j])) {
            B[k] = A[i];
            i = i + 1;
        } else {
            B[k] = A[j];
            j = j + 1;
        }
    }
}


void CopyArray(int A[], int iBegin, int iEnd, int B[])
{
    for(int k = iBegin; k < iEnd; k++)
        B[k] = A[k];
}



int median_sort_buffer[32];


int analog_8x_median( int channel ) {
  int raw[8];
  int dummy = analogRead( channel ); // cold-start, throw away
  
  raw[0] = analogRead( channel );
  raw[1] = analogRead( channel );
  raw[2] = analogRead( channel );
  raw[3] = analogRead( channel );
  raw[4] = analogRead( channel );
  raw[5] = analogRead( channel );
  raw[6] = analogRead( channel );
  raw[7] = analogRead( channel );

  // sort raw -> back into raw
  TopDownMergeSort( raw, median_sort_buffer, 8 );

  /* debugging only
  for( int i=0; i < 8; i++ ) {
    Serial.println( raw[i] ); Serial.print( "\t" );
  }
  Serial.println();
  */

  // int value = (raw[2]+raw[3]+raw[4]+raw[5]) >> 2;
  // int value = (raw[3]+raw[4]) >> 1; // too noisy
  int value = (raw[0]+raw[1]+raw[2]+raw[3]) >> 2;
  // int value = (raw[0]+raw[1]) >> 1; // ok on usb, very very spiky on lipo 3.7v + step-up
  
  return value;
}



void setup() {
  // initial blinking, informing the user in case of no Serial connected...
  // 
  pinMode( LED_PIN, OUTPUT );
  
  // try to open serial port, remember in have_serial
  //
  if (try_serial) {
    for( int n=0; n < MAX_SERIAL_ATTEMPTS; n++ ) {
      // open serial communications and wait for port to open:
      Serial.begin( 500000 ); // 115200 9600
      delay( 1000 );
 
      if (Serial) { 
        have_serial = 1; 
        msg( "Instrumented Screwdriver v3..." );
        break; 
      }
    }
    info_blink_led( 1, 1, 1 ); // 1x long short short short short short
  }

  // digital and analog I/O pins setup
  //
  analogReadResolution( 10 );

  // Initialize Analog Controller
  // Setting clock
  while(GCLK->STATUS.reg & GCLK_STATUS_SYNCBUSY);

  GCLK->CLKCTRL.reg = GCLK_CLKCTRL_ID( GCM_ADC ) | // Generic Clock ADC
                      GCLK_CLKCTRL_GEN_GCLK0     | // Generic Clock Generator 0 is source
                      GCLK_CLKCTRL_CLKEN ;

  while( ADC->STATUS.bit.SYNCBUSY == 1 );          // Wait for synchronization of registers between the clock domains

  ADC->CTRLB.reg = ADC_CTRLB_PRESCALER_DIV64 |    // was: 512 Divide Clock by 512, then 128 (v2), now 64.
                   ADC_CTRLB_RESSEL_10BIT;         // 10 bits resolution as default

  ADC->SAMPCTRL.reg = 0x0f; // was: 0x3f;                        // Set max Sampling Time Length

  while( ADC->STATUS.bit.SYNCBUSY == 1 );          // Wait for synchronization of registers between the clock domains

  ADC->INPUTCTRL.reg = ADC_INPUTCTRL_MUXNEG_GND;   // No Negative input (Internal Ground)

  // Averaging (see datasheet table in AVGCTRL register description)
  ADC->AVGCTRL.reg = ADC_AVGCTRL_SAMPLENUM_1 |    // 1 sample only (no oversampling nor averaging)
                     ADC_AVGCTRL_ADJRES(0x0ul);   // Adjusting result by 0

  analogReference( AR_DEFAULT ) ; // Analog Reference is AREF pin (3.3v)


  // optocoupler setup for the screwdriver "tool plate". 
  // D10-D11-D12 drive chains of two emitter LEDs each,
  // while A0 and A1 are connected to the upper/lower phototransistors of
  // each chain...
  pinMode( 10, OUTPUT ); // dark red, left-right LEDs
  pinMode( 11, OUTPUT ); // gray, center LED
  pinMode( 12, OUTPUT ); // bright red, top-bottom LEDs

  pinModeHighDriveStrength( 10, true );
  pinModeHighDriveStrength( 11, true );
  pinModeHighDriveStrength( 12, true );
  
  pinMode( A0, INPUT ); // top-left (front-view of the LEDs)
  pinMode( A1, INPUT ); // bottom-right (front-view of the LEDs)
  pinMode( A2, INPUT ); // center LED

  // PULLUPs dont work? try digitalWrite...
  digitalWrite( A0, HIGH );
  digitalWrite( A1, HIGH );
  digitalWrite( A2, HIGH );

  // optocoupler setup for the graping handle with six chains
  // of two optocouplers, driven by D3-D4-D5-D6-D7-D8. 
  // Phototransistors are connected to A6 and A7.
  pinMode( 3, OUTPUT );
  pinMode( 4, OUTPUT );
  pinMode( 5, OUTPUT );
  pinMode( 6, OUTPUT );
  pinMode( 7, OUTPUT );
  pinMode( 8, OUTPUT );

  pinModeHighDriveStrength( 3, true );  
  pinModeHighDriveStrength( 4, true );  
  pinModeHighDriveStrength( 5, true );  
  pinModeHighDriveStrength( 6, true );  
  pinModeHighDriveStrength( 7, true );  
  pinModeHighDriveStrength( 8, true );  
  
  // pinMode( A3, INPUT_PULLUP );
  // note: A4=SDA 
  // note: A5=SCL
  pinMode( A6, INPUT );
  pinMode( A7, INPUT );

  info_blink_led( 1, 2, 1 ); // I/O setup ok

  // initialize IMU, enter error loop if this fails.
  //
  if (!IMU.begin()) {
    msg( "Failed to initialize the IMU! Stopped." );
    error_blink_forever( 3 );
  }

  info_blink_led( 1, 3, 1 ); // IMU ok

  // check for the WiFi module:
  //
  int attempts = 0;
  if (use_wifi) {
    if (WiFi.status() == WL_NO_MODULE) {
      msg( "Communication with WiFi module failed! Stopped." );
      error_blink_forever( 4 );
    }

    String fv = WiFi.firmwareVersion();
    if (fv < "1.0.0") {  
      msg( "Please upgrade the WifiNINA firmware" );
    }

    // attempt to connect to Wifi network:
    while (status != WL_CONNECTED) {
      if (have_serial) {
        Serial.print( "Attempting to connect to SSID: " );
        Serial.println(ssid);
      }
    
      // Connect to WPA/WPA2 network. Change this line if using open or WEP network:
      status = WiFi.begin( ssid, pass );

      info_blink_led( 2, 2, 1 );
      
      status = WiFi.status();
      for( int j=0; j < 30; j++ ) {
        if (status == WL_CONNECTED) break;
        status = WiFi.status();
        if (have_serial) { Serial.print( "Wifi status is " ); Serial.print( status ); Serial.print( " attempts: " ); Serial.println( attempts ); }
        delay( 500 );
      }
    }
  }

  // disable low-power modes
  if (use_wifi) {
    msg( "Connected to WiFi!" );
    if (have_serial) printWifiStatus();

     WiFi.noLowPowerMode();
     Udp.begin( localPort );
  }

  info_blink_led( 1, 4, 1 );

  iteration = 0;
  
} // end setup


long lastLedSwitchMicros = 0;
long lastLedSwitchState = 0;

float ax, ay, az;
float gx, gy, gz;
int iax, iay, iaz, igx, igy, igz;




void loop() {
  iteration ++;
  pp = packetBuffer;

  long t0 = micros();
  if ((t0 - lastLedSwitchMicros) > 250000L) {
    lastLedSwitchMicros = t0;
    lastLedSwitchState ^= 1;
    digitalWrite( LED_PIN, lastLedSwitchState );
  }

  // pins D12-D13-D14 drive the LEDs on the tool-plate,
  // analog inputs are A0 and A1. Read each analog channel
  // a few times to ensure stable values behind the ADC
  // analog multiplexer.
  //
  // 2020.01.25: we need extra pause when switching muxes, 
  // probably due the response time of the phototransistor.
  // At the moment, sample A0,A2, then sample A1, then sample A0,A2 again.
  // This needs to be considered also for the grasp handle sensors...
  // 
  int t1 = micros();

  int nt = sprintf( pp, "D %d T", iteration );
  pp += nt;
  
  digitalWrite( 10, HIGH );
  digitalWrite( 11, LOW );
  digitalWrite( 12, LOW );
  force0 = sampleADCIntoPacket( A0, 3 ); // adc_warmup );
  force1 = sampleADCIntoPacket( A2, 1 ); // adc_warmup );

  digitalWrite( 10, LOW );
  digitalWrite( 11, LOW );
  digitalWrite( 12, HIGH ); 
  force2 = sampleADCIntoPacket( A0, 5 ); // adc_warmup );
  force3 = sampleADCIntoPacket( A2, 1 ); // adc_warmup );

  digitalWrite( 10, LOW );
  digitalWrite( 11, HIGH );
  digitalWrite( 12, LOW );
  force4 = sampleADCIntoPacket( A1, 3 ); // adc_warmup );
  force5 = 0;


  digitalWrite( 10, LOW );
  digitalWrite( 11, LOW );
  digitalWrite( 12, LOW );


  // read grasp-handle forces from channels A6+A7
  // 
  int t2 = micros();
  int nh = sprintf( pp, " H" );
  pp += nh;
  
  one_hot( 0x04 ); 
  touch_0_lower = sampleADCIntoPacket( A6, 2 ); // master (blue ribbon cable, near USB cable pos)
  touch_0_upper = sampleADCIntoPacket( A7, 2 );

  one_hot( 0x08 );
  touch_1_lower = sampleADCIntoPacket( A6, 2 ); // purple
  touch_1_upper = sampleADCIntoPacket( A7, 2 );

  one_hot( 0x10 );
  touch_2_lower = sampleADCIntoPacket( A6, 2 ); // gray, above antenna
  touch_2_upper = sampleADCIntoPacket( A7, 2 );

  one_hot( 0x20 );
  touch_3_lower = sampleADCIntoPacket( A6, 2 ); // green 
  touch_3_upper = sampleADCIntoPacket( A7, 2 );

  one_hot( 0x40 );
  touch_4_lower = sampleADCIntoPacket( A6, 2 ); // orange
  touch_4_upper = sampleADCIntoPacket( A7, 2 ); 

  one_hot( 0x80 );
  touch_5_lower = sampleADCIntoPacket( A6, 2 ); // red
  touch_5_upper = sampleADCIntoPacket( A7, 2 );

  one_hot( 0x00 );

  // read IMU values (if available)
  // 

  int t3 = micros();
  if (IMU.gyroscopeAvailable()) {
    IMU.readGyroscope( gx, gy, gz );
    igx = (int) (gx * GYRO_TO_INT);
    igy = (int) (gy * GYRO_TO_INT);
    igz = (int) (gz * GYRO_TO_INT);
  }
  if (IMU.accelerationAvailable()) {
    IMU.readAcceleration( ax, ay, az );
    iax = (int) (ax * ACC_TO_INT);
    iay = (int) (ay * ACC_TO_INT);
    iaz = (int) (az * ACC_TO_INT);
  }

  int ng = sprintf( pp, " G %d %d %d", igx, igy, igz );
  pp += ng;
  
  int na = sprintf( pp, " A %d %d %d", iax, iay, iaz );
  pp += na;
                        
  *pp= '\n'; pp++;
  *pp = 0; pp++;
  

  int t4 = micros();

  if (use_wifi) {
    Udp.beginPacket( tamsXXX, 11333 ); 
    int nb = (pp - packetBuffer);
    Udp.write(packetBuffer, nb );
    Udp.endPacket();
  }

  int t5 = micros();

  if (have_serial) {
    Serial.print( "loop took " ); Serial.print( (t5-t1) ); Serial.print( " usec." );
    Serial.print( "forces,grasps,imu,udp took " );
    Serial.print( (t2-t1) ); Serial.print( " " );
    Serial.print( (t3-t2) ); Serial.print( " " );
    Serial.print( (t4-t3) ); Serial.print( " " );
    Serial.print( (t5-t4) ); Serial.println( " " );
  }
  
  if (have_serial) {
    Serial.print( packetBuffer );           
    // Serial.flush();
  }
  
  // wait to see if a reply is available
  // delay(10); // results in ~60Hz without ADC reads
  // delay( 1 );

  if (use_wifi && use_wifi_input) {
    if (Udp.parsePacket()) {
      if (have_serial) Serial.println("packet received: `");
        // We've received a packet, read the data from it
      Udp.read(packetBuffer, PACKET_SIZE); // read the packet into the buffer
      if (have_serial) Serial.print( packetBuffer ); // echo incoming command to serial 
    }
  }
}


void printWifiStatus() {
  // print the SSID of the network you're attached to:
  Serial.print("SSID: ");
  Serial.println(WiFi.SSID());

  // print your board's IP address:
  IPAddress ip = WiFi.localIP();
  Serial.print("IP Address: ");
  Serial.println(ip);

  // print the received signal strength:
  long rssi = WiFi.RSSI();
  Serial.print("signal strength (RSSI):");
  Serial.print(rssi);
  Serial.println(" dBm");
}


void one_hot( unsigned int mask ) {

  digitalWrite( 3, (mask&0x04) > 0 ? HIGH : LOW );
  digitalWrite( 4, (mask&0x08) > 0 ? HIGH : LOW );
  digitalWrite( 5, (mask&0x10) > 0 ? HIGH : LOW );
  digitalWrite( 6, (mask&0x20) > 0 ? HIGH : LOW );
  digitalWrite( 7, (mask&0x40) > 0 ? HIGH : LOW );
  digitalWrite( 8, (mask&0x80) > 0 ? HIGH : LOW );
  /* */
}


int sampleADC_spiky( int pin, int start_adc_warmup ) {
  int value;
  for( int i=0; i < start_adc_warmup; i++ ) {
    value = analogRead( pin );
  }
  return value;  
}


static int dummy; // don't let the compiler optimize this away...

/**
 * sample the given analog input pin, using the given number of ADC warmup cycles.
 * Afterwards, we sample the pin a few times and return the average value.
 */
int sampleADC( int pin, int start_adc_warmup ) {

  // start_adc_warmup = 0;
  for( int i=0; i < start_adc_warmup; i++ ) {
    dummy += analogRead( pin );
  }

  /*
  int v1 = analogRead( pin );
  int v2 = analogRead( pin );
  return (v1+v2)/2;
  */ 
  // return analogRead( pin );
  
  int v1 = analogRead( pin );
  int v2 = analogRead( pin );
  int v3 = analogRead( pin );
  
  return min( v3, min( v1, v2 )); // Wifi spikes mean higher current, lower supply voltage, less light, lower phototransistor current, higher ADC readout
}


/**
 * sample given ADC channel and write value into packetBuffer at current
 * pp pointer position. Finally, return sampled analog value,
 */
int sampleADCIntoPacket( int pin, int start_adc_warmup ) {
  // int value = sampleADC( pin, start_adc_warmup ); // v2
  int value = analog_8x_median( pin ); // v3
  int nchars = sprintf( pp, " %d", value );
  pp += nchars;

  if (have_serial && debug) {
    Serial.print( "sampleADCIntoPacket: pin " ); Serial.print( pin );
    Serial.print( " value " ); Serial.print( value );
    Serial.print( " nchars " ); Serial.print( nchars );
    Serial.print( " pp " ); Serial.print( (pp - packetBuffer) );
    Serial.println();
  }
  
  return value;
}



/**
 * select high (True) or low (false) drive strength on given digital I/O pin.
 * See SAMD docs and "variants.h" for details.
 */
void pinModeHighDriveStrength( uint32_t ulPin, boolean b ) {
  uint8_t val = (uint8_t) (PORT_PINCFG_INEN);
  if (b == true) val |= (uint8_t) (PORT_PINCFG_DRVSTR);
  
  PORT->Group[g_APinDescription[ulPin].ulPort].PINCFG[g_APinDescription[ulPin].ulPin].reg = val;
  //    = (uint8_t)(PORT_PINCFG_INEN | PORT_PINCFG_DRVSTR) ;
  PORT->Group[g_APinDescription[ulPin].ulPort].DIRSET.reg = (uint32_t)(1<<g_APinDescription[ulPin].ulPin) ;
}

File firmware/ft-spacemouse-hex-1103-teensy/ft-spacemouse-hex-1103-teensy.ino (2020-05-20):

/* ft-spacemouse-hex-1103-teensy.ino

  "spacemouse v2"
  
  Six-axis Force/Torque sensor using Teensy 3.2 microcontroller and
  six Vishay TCST 1103 optocouplers / fork-type interrupters. The sensors 
  are placed on a circle, 60 degrees apart, with even-numbered sensors 
  intended to measure distance from the moving plate, while odd-numbered
  sensors measure plate rotation.

  This program just periodically reads the analog inputs A0 ..A5, and 
  writes the data to serial line at 115200 baud for > 100Hz samplerate.
  Combine with ROS tams_printed_ft/nodes/spacemouse.py to publish
  raw data and (once calibrated) geometry_msgs/WrenchStamped data.

  Optical feedback of device status:

  - LED blinking fast-fast-fast-fast-long: device init, 
    waiting for serial communication,
  - LED on: device operating,
  - LED fast blinking (5 Hz): overload condition (during last second),
  
  - TODO: check for hardware errors (broken cables, missing VCC, etc)
    and indicate with different blinking patterns.

  Blinking the on-board LED (~10 mA) actually disturbs the sensor readings,
  so the originally planned heartbeat signal is now disabled and replaced
  by continuous LED on during normal operation.

  Note that the Teensy A/D converter shows weird jumps in its output
  values near 50% full range, 25%/75% full range - when using the 
  internal pullup resistors. Therefore, we now use external 47kOhm resistors 
  routed from analog pins A0..A5 to the digital pins on the opposite side 
  of the Teensy board, with the digital pins driven high. To reduce noise,
  we also use a bit of exponential averaging on the analog channels.
  
  TeensyDuino source code and compiler config is here:

  ~/arduino-1.8.9/hardware/teensy/avr/cores/teensy3


  Sensor layout and wiring was done in an ad-hoc manner on the prototype; you 
  may want to order the sensors in sequence when you build your own sensor.
  
  Using a top-view of the main sensor plate, with the USB connector and the
  indicator notch at the 12-o'clock position, we have:

  1  o'clock: channel #2 (up/down)
  3  o'clock: channel #1 (sideways)
  5  o'clock: channel #4 (up/down)
  7  o'clock: channel #5 (sideways)
  9  o'clock: channel #0 (up/down)
  11 o'clock: channel #3 (sideways)

  black       - GND (common)
  matte red   - 5V IR LED supply current (need ~40mA total for 6 LEDs)


  IR emitter series resistors:

  Designed for 5V supply (either USB or regulated external supply),
  LEDs connected in pairs with common series resistor, currently
  using 180 ohm resistors, for a forward current in the middle of
  the recommended TCST1103 range (TODO: check values, original
  hardware integration documentation lost):
  
  I_LED ~ (5.0 - 2*1.2)V / 180 ohm = 14 mA


  2020.01.05 - calibrated using ATi nano17, also took rviz screencast
  2020.01.05 - testing, used (and filed) new moving plate
  2020.01.05 - add external 47kOhm pullup resistors
  2020.01.04 - add error blinking logic, use arrays throughout
  2020.01.03 - convert from older 2017/2018 sketches
  
 (c) 2017, 2018, 2020, hendrich@informatik.uni-hamburg.de  
*/
 
 
#include <stdio.h>
 
// current sensor readings 
int channel[6] = { 0, 0, 0, 0, 0, 0 };

// previous sensor readings for exponential averaging
int prev[6] = { 0, 0, 0, 0, 0, 0 };

#define ADC_12_BIT
#undef  ADC_10_BIT

#ifdef ADC_10_BIT
// hardcoded lower/upper "overload" limits, 10 bit
int lower[6] = {  50, 100,  50, 100,  50, 100 };
int upper[6] = { 950, 950, 950, 950, 900, 950 };
#else
int lower[6] = {  400,  400,  400,  400,  400,  400 };
int upper[6] = { 3800, 3800, 3800, 3800, 3800, 3800 };
#endif



int latest_overload_millis = 0; // no overload yet
int latest_blink_millis = 0;
 
int iteration;
int led = 0;
#define LED_PIN 13

char buffer[120];


void setup() {
  // we use analog pins A0..A5, but do we want the internal pullups?
  // fnh 2020.01.03: Teensy ADC actually does not work with INPUT_PULLUP,
  // which introduces strange value-"jumps" near 50% full-range.
  //

#ifdef ADC_12_BIT  
  analogReadResolution( 12 ); // up to 13, but the "jumps" only get worse
#else
  analogReadResolution( 10 ); // mostly noise-free baseline
#endif

  // analogReference( AR_INTERNAL2V23 );
  // analogReference( INTERNAL );

  // we connect the pullup resistors needed for the phototransistors
  // to digital outputs driven high; routing is straight across the
  // Teensy...
  pinMode( 11, OUTPUT ); digitalWrite( 11, HIGH );
  pinMode( 10, OUTPUT ); digitalWrite( 10, HIGH );
  pinMode(  9, OUTPUT ); digitalWrite(  9, HIGH );
  pinMode(  8, OUTPUT ); digitalWrite(  8, HIGH );
  pinMode(  7, OUTPUT ); digitalWrite(  7, HIGH );
  pinMode(  6, OUTPUT ); digitalWrite(  6, HIGH );
  
  // status LED pin, heartbeat blinking
  pinMode( LED_PIN, OUTPUT);

  // initialize serial communication at 9600 bits per second:
  Serial.begin(115200);

  // on recent Linux, somehow Teensy 3.x will not start serial communication,
  // see discussion here:
  // https://forum.pjrc.com/threads/55732-Problem-Connecting-Teensy-to-Raspberry-Pi-with-USB?p=203769#post203769
  // 
  // One other tip was to select the "Serial + Midi" profile when programming
  // to avoid the "dead" serial port...
  //
  // For now, show a 4x-fast-pause blinking during waiting for Serial. 
  // to tell the user that communication is not working yet:
  //
  while( !Serial) { // wait for serial port to connect. Needed for native USB port only
    for( int i=0; i < 4; i++ ) { // fast-fast-fast-fast-pause identifies this program
      digitalWrite( LED_PIN, 1 );
      delay( 200 ); 
      digitalWrite( LED_PIN, 0 );
      delay( 200 ); 
    }
    delay( 700 ); 
  }
} // end setup()
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

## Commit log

2020-05-03 Add screenshot of sensors in rviz (showing URDF models and gazebo simulation).
2020-05-15 Upload meshes and URDF/xacro description of the prototypes described in the paper.
    [adjustable_ft.xacro, adjustable_ft_demo.xacro, ati_nano17.stl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]
2020-05-15 Update payload for simulated block_ft sensor.
    [gazebo_all_ft_demo.xacro]
2020-05-15 Add launch files and controller configurations for gazebo simulation.
    [gazebo_adjustable_ft_demo_controllers.yaml, gazebo_all_ft_demo_controllers.yaml, gazebo_ati_nano17_ft_demo_controllers.yaml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]
2020-05-15 Add info about URDF models and gazebo demo script.
2020-05-15 Add OpenSCAD 'vitamins' (libraries) and ft-pushing-box sensor.
    [breadboard.scad, electronics.scad, ft-pushing-box.scad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]
2020-05-15 Add 00readme.txt for the OpenSCAD models.
    [optokoppler.scad]
2020-05-18 Add 2DOF-sensor-module "soldering tool" model.
    [2DOF_soldering_tool.scad]
2020-05-18 Updated soldering tool model; also added png preview.
    [2DOF_soldering_tool.scad, 2DOF_soldering_tool.stl]
2020-05-20 Add ft-pushing-box firmware for Arduino nano.
2020-05-20 Add firmware for "block_ft" sensor: 8x ITR8307 reflex sensors, Arduino nano.
2020-05-20 Add firmware for "big_ft" sensor using 8x Vishay TCST1103 photointerrupters.
2020-05-20 Add firmware for "bottle_ft" sensor (for pouring experiments).
2020-05-20 Add firmware for the six-sensor "spacemouse" prototypes.
2020-05-20 Add firmware for the instrumented screwdriver (WiFI, IMU, multiplexed optical sensors).
2020-05-20 Add STL-format meshes for the "ft-pushing-box" sensor.
    [ft-pushing-box-bottom-plate.stl, ft-pushing-box-coins-holder.stl, ft-pushing-box-complete-without-probe.stl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]
2020-05-20 Add OpenSCAD model and STL meshes of the "adjustable_ft" ("big_ft") sensor.
    [adjustable-ft-v1-base-ring.stl, adjustable-ft-v1-distance-ring-2mm.stl, adjustable-ft-v1-fin-ring.stl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]
2020-05-22 Add OpenSCAD model and STL meshes for the "block-ft" 8x reflex sensor.
    [block-ft-base-holder.stl, block-ft-base-plate.stl, block-ft-cover-ring-40-height-10.stl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]
2020-05-22 Added export script and re-exported STL meshes.
    [adjustable-ft-v1-base-ring.stl, adjustable-ft-v1-distance-ring.stl, adjustable-ft-v1-fin-ring.stl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]
2020-05-22 Upload sample ROS nodes for the pushing-box and block-ft sensors.
2020-08-08 Add bottle-ft sensor model and meshes.
    [bottle-six-axis-ft-v2-base-ring-h12.stl, bottle-six-axis-ft-v2-base-ring-h15.stl, bottle-six-axis-ft-v2-grasp-handle-70mm.stl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]
